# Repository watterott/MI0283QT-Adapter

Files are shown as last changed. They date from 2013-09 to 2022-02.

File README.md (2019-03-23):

# MI0283QT-Adapter
Adapter Board with 2.8" TFT-Display and Touchscreen/Touchpanel.

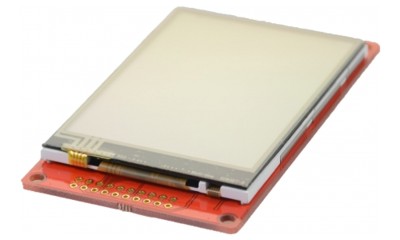
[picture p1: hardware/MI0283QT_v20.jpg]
MI0283QT-Adapter


* Multi-Inno MI0283QT 2.8" Display with Touchpanel (320x240 pixel)
* Backlight dimmable
* 3.3V - 5V tolerant IOs
* Power: 3.3V - 5V
* **MI0283QT-Adapter v1**
  * TI ADS7846/TSC2046 Touch-Controller
  * Interface: SPI/SSI (8-Bit or 9-Bit, up to 32MHz)
* **MI0283QT-Adapter v2**
  * NXP LPC1114 ARM Cortex-M0 with Open-Source Firmware
  * Interface: UART, I2C, SPI/SSI (8-Bit, Mode 3, up to 4MHz)
  * Pin-compatible with MI0283QT-Adapter v1
* Open-Source and released under the [Creative Commons Attribution Share-Alike License](https://creativecommons.org/licenses/by-sa/4.0/).
* **[Documentation on learn.watterott.com](https://learn.watterott.com)**

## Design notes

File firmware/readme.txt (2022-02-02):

Display Firmware
================
Firmware for MI0283QT-Adapter v2 and GLCD-Shield (with LPC1114 ARM Cortex-M0).
Visit https://github.com/watterott/MI0283QT-Adapter for updates.

Supported IDEs: CrossWorks for ARM and LPCXpresso/MCUxpresso

Documentation
-------------
  See docu.md

Third party software
--------------------
  CMSIS
  http://www.arm.com/products/processors/cortex-m/cortex-microcontroller-software-interface-standard.php

License
-------
  See license.txt

History
-------
  Jan 26 2022  v0.08  Added CMD_LCD_ENABLE + CMD_LCD_DISABLE.

  Jun 30 2014  v0.07  Bugfix in set_pwm.

  Jun 08 2014  v0.06  Bugfix in CMD_LCD_ORIENTATION+CMD_LCD_DRAWTEXT.
                      Bugfix in CMD_LCD_DRAWIMAGE.
                      Bugfix in touch calibration routine.
                      Added CMD_SYNC.

  Dec 09 2013  v0.05  Compiling with LPCXpresso.
                      Added interrupt/status output.

  Sep 18 2013  v0.04  Added ADC read function.

  Aug 18 2013  v0.03  Added byte order setting.

  Jun 22 2013  v0.02  TP/ENC/NAV have to be enabled.
                      Added light sensor support.

  Jun 17 2013  v0.01  First release.

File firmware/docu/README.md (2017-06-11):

# Display Firmware

**Documentation for Firmware v0.06+**

## Firmware Update

See [Firmware Update Guide](https://github.com/watterott/MI0283QT-Adapter/blob/master/firmware/update_guide/README.md).

The source code can be compiled with [CrossWorks for ARM](http://www.rowley.co.uk/arm/index.htm) or [LPCXpresso](http://www.lpcware.com/lpcxpresso) (registered Free Edition).

## Interfaces

The display can be controlled through 3 interfaces: I2C, SPI/SSI and UART. The default interface is I2C.
To activate SPI or UART set **CS+MOSI** or **CS+RX** to low after a reset or on power-up.
The current interface can be saved as default with the software command ```CMD_CTRL_SAVE``` and changed with ```CMD_CTRL_INTERFACE```.

**Default settings:**

* Interface: I2C
* Byte order: big endian
* I2C: address 0x20, max. 400 kHz
* SPI: Mode 3, max. 4 MHz @ 48 MHz system clock
* UART: 9600 baud (8N1)
* System clock: 48 MHz

**I2C activation:**

    - Set MOSI high + RX high + CS low
    - Reset: RST low -> wait 10 ms -> RST high

**SPI activation:**

    - Set MOSI low + RX high + CS low
    - Reset: RST low -> wait 10 ms -> RST high

**UART activation:**

    - Set RX low + MOSI high + CS low
    - Reset: RST low -> wait 10 ms -> RST high

## Examples

* [Arduino examples](https://github.com/watterott/MI0283QT-Adapter/tree/master/firmware/examples)

## Commands

Parameters have a 8 bit width, expect *color values* (RGB565) and *position values* (x,y,z,w,h,r) on screens bigger than 255 pixel in one direction. These are 16 bit width.

Commands that end with *FG* or *BG* need no color value.

Example: ```CMD_LCD_CLEAR``` has as parameter a 2 byte color value and ```CMD_LCD_CLEARFG``` fills the screen with the foreground color and ```CMD_LCD_CLEARBG``` with the background color.

### General Commands

    CMD_NOP1
    CMD_NOP2
No operation.

    CMD_SYNC
Returns ```CMD_SYNC``` (1 byte).

    CMD_VERSION
Get firmware version. Returns 4 bytes, for example ```0.12```.

    CMD_TEST
Start the test program. To exit send ```0``` and wait till the board responses with ```CMD_TEST``` (1 byte).

    CMD_STATUS
Get status. A reading clears the interrupt output. Returns 1 byte with ```FEATURE_LCD```, ```FEATURE_TP```, ```FEATURE_ENC```, ```FEATURE_NAV```, ```FEATURE_LDR``` set.

    CMD_FEATURES
Get features. Returns 1 byte with ```FEATURE_LCD```, ```FEATURE_TP```, ```FEATURE_ENC```, ```FEATURE_NAV```, ```FEATURE_LDR```, ```FEATURE_IRQ``` set.

    CMD_PIN
Set GPIO pin. Parameter: 1 byte (1=input, 2=read input, 3=output low, 4=output high, 5=IRQ output low active, 6=IRQ output high active)

    CMD_ADC
Read ADC channel. Parameter: 1 byte (4, 5, 7 or 255 for LDR)

    CMD_CTRL
General system settings/options. Parameter: 1 byte
* ```CMD_CTRL_SAVE```      - Save current settings to flash (sysclock, backlight, interface, baud rate, address, byte order, fg color, bg color, touchpanel calibration).
* ```CMD_CTRL_INTERFACE``` - Set interface. Parameter: 1 byte (```INTERFACE_UART```, ```INTERFACE_I2C```, ```INTERFACE_SPI```)
* ```CMD_CTRL_BAUDRATE```  - Set UART baud rate. Parameter: 4 bytes = 32 bit (9600...1000000)
* ```CMD_CTRL_ADDRESS```   - Set I2C address. Parameter: 1 byte
* ```CMD_CTRL_BYTEORDER``` - Set byte order. Parameter: 1 byte (0=big endian , 1=little endian)
* ```CMD_CTRL_SYSCLOCK```  - Set system clock in MHz. Parameter: 1 byte (12, 16, 24, 32, 36, 48)
* ```CMD_CTRL_FEATURES```  - Enable or disable features. Parameter: 1 byte (```FEATURE_LCD```, ```FEATURE_TP```, ```FEATURE_ENC```, ```FEATURE_NAV```, ```FEATURE_LDR```, ```FEATURE_IRQ```)

### Display Commands

    CMD_LCD_LED
Set or get display backlight power. Parameter: 1 byte (0-100 or 255 for reading)

    CMD_LCD_RESET
Reset the display controller.

    CMD_LCD_POWER
Set display panel power. Parameter: 1 byte (0=off, 1=on)

    CMD_LCD_RAWCMD
Send raw command to the display controller. Parameter: 1 byte
    
    CMD_LCD_RAWDAT
Send raw data to the display controller. Parameter: 1 byte
    
    CMD_LCD_ORIENTATION
Set display orientation. Parameter: 1 byte (0=0°, 9=90°, 18=180°, 27=270°)

Orientation dia

    CMD_LCD_WIDTH
Get display width. Returns always 2 bytes = 16 bit.
    
    CMD_LCD_HEIGHT
Get display height. Returns always 2 bytes = 16 bit.
    
    CMD_LCD_INVERT
Invert display. Parameter: 1 byte (0=off, 1=on)
    
    CMD_LCD_FGCOLOR
Set foreground color. Parameter: color (2 byte, RGB565)
    
    CMD_LCD_BGCOLOR
Set background color. Parameter: color (2 byte, RGB565)
    
    CMD_LCD_TERMINAL
Start terminal mode. To exit send *0* and the board responses with ```CMD_LCD_TERMINAL```.

    CMD_LCD_DRAWIMAGE
Draw image. Parameter: x0, y0, w, h, color_mode, color...
    
    CMD_LCD_CLEAR
    CMD_LCD_CLEARFG
    CMD_LCD_CLEARBG
Clear display. Parameter: [color]

    CMD_LCD_DRAWPIXEL
    CMD_LCD_DRAWPIXELFG
    CMD_LCD_DRAWPIXELBG
Draw pixel. Parameter: x0, y0, [color]

    CMD_LCD_DRAWLINE
    CMD_LCD_DRAWLINEFG
    CMD_LCD_DRAWLINEBG
Draw line. Parameter: x0, y0, x1, y1, [color]

    CMD_LCD_DRAWLINES
    CMD_LCD_DRAWLINESFG
    CMD_LCD_DRAWLINESBG
Draw lines. Parameter: [color], n, x0, y0...xn, yn

    CMD_LCD_DRAWRECT
    CMD_LCD_DRAWRECTFG
    CMD_LCD_DRAWRECTBG
Draw rectangle. Parameter: x0, y0, w, h, [color]

    CMD_LCD_FILLRECT
    CMD_LCD_FILLRECTFG
    CMD_LCD_FILLRECTBG
Fill rectangle. Parameter: x0, y0, w, h, [color]

    CMD_LCD_DRAWRNDRECT
    CMD_LCD_DRAWRNDRECTFG
    CMD_LCD_DRAWRNDRECTBG
Draw round rectangle. Parameter: x0, y0, w, h, radius, [color]

    CMD_LCD_FILLRNDRECT
    CMD_LCD_FILLRNDRECTFG
    CMD_LCD_FILLRNDRECTBG
Fill round rectangle. Parameter: x0, y0, w, h, radius, [color]

    CMD_LCD_DRAWCIRCLE
    CMD_LCD_DRAWCIRCLEFG
    CMD_LCD_DRAWCIRCLEBG
Draw circle. Parameter: x0, y0, radius, [color]

    CMD_LCD_FILLCIRCLE
    CMD_LCD_FILLCIRCLEFG
    CMD_LCD_FILLCIRCLEBG
Fill circle. Parameter: x0, y0, radius, [color]

    CMD_LCD_DRAWELLIPSE
    CMD_LCD_DRAWELLIPSEFG
    CMD_LCD_DRAWELLIPSEBG
Draw ellipse. Parameter: x0, y0, radius_x, radius_y, [color]

    CMD_LCD_FILLELLIPSE
    CMD_LCD_FILLELLIPSEFG
    CMD_LCD_FILLELLIPSEBG
Fill ellipse. Parameter: x0, y0, radius_x, radius_y, [color]

    CMD_LCD_DRAWTEXT
    CMD_LCD_DRAWTEXTFG
    CMD_LCD_DRAWTEXTBG
Draw text. Parameter: [fg_color], [bg_color], x0, y0, size_clear (0x7F=size, 0x80=clear background), length, text

    CMD_LCD_DRAWSTRING
    CMD_LCD_DRAWSTRINGFG
    CMD_LCD_DRAWSTRINGBG
Draw string. Parameter: [fg_color], [bg_color], x0, y0, size_clear (0x7F=size, 0x80=clear background), text (end with 0x00)

### Touch-Panel Commands

Note: To activate the touch panel use ```CMD_CTRL + CMD_CTRL_FEATURES``` and set ```FEATURE_TP```.
      The touch panel will be checked in background continuously and the result can be read with the following commands.

    CMD_TP_POS
Get last position and pressure. Returns x, y, z.

    CMD_TP_X
Get last x position. Returns x.

    CMD_TP_Y
Get last y position. Returns y.

    CMD_TP_Z
Get current pressure. Returns z.

    CMD_TP_WAITPRESS
Wait till press and get position after press. Returns x, y.

    CMD_TP_WAITRELEASE
Wait till release and get position after release. Returns x, y.

    CMD_TP_WAITMOVE
Wait till move and get direction after move. Returns 1 byte (0x01=x-, 0x02=x+, 0x04=y-, 0x08=y+).

    CMD_TP_CALIBRATE
Calibrate touch panel. This will not save the calibration data to flash (see ```CMD_CTRL + CMD_CTRL_SAVE```). Returns ```CMD_TP_CALIBRATE``` after the calibration is completed or when *0* is sent to exit.

### Rotary-Encoder Commands

Note: To activate the rotary encoder use ```CMD_CTRL + CMD_CTRL_FEATURES``` and set ```FEATURE_ENC```.
      The encoder state will be checked in background continuously and the result can be read with the following commands.

    CMD_ENC_POS
Get position and switch state. Returns 2 bytes: position (-127...+127), state (0x01=press, 0x02=long press).

    CMD_ENC_SW
Get switch state. Returns 1 byte (0x01=press, 0x02=long press)

    CMD_ENC_WAITPRESS
Wait till press. Returns 2 bytes: position (-127...+127), state (0x01=press, 0x02=long press).

    CMD_ENC_WAITRELEASE
Wait till release. Returns 2 bytes: position (-127...+127), state (0x01=press, 0x02=long press).

### Navigation-Switch / Joystick Commands

Note: To activate the navigation switch use ```CMD_CTRL + CMD_CTRL_FEATURES``` and set ```FEATURE_NAV```.
      The switch will be checked in background continuously and the result can be read with the following commands.

    CMD_NAV_POS
Get position and switch state. Returns 3 bytes: left-right position (-127...+127), down-up position (-127...+127), state (0x01=press, 0x02=long press, 0x10=right, 0x20=left, 0x40=up, 0x80=down).

    CMD_NAV_SW
Get switch state. Returns 1 byte: state (0x01=press, 0x02=long press, 0x10=right, 0x20=left, 0x40=up, 0x80=down)

    CMD_NAV_WAITPRESS
Wait till press. Returns 3 bytes: left-right position (-127...+127), down-up position (-127...+127), state (0x01=press, 0x02=long press, 0x10=right, 0x20=left, 0x40=up, 0x80=down).

    CMD_NAV_WAITRELEASE
Wait till release. Returns 3 bytes: left-right position (-127...+127), down-up position (-127...+127), state (0x01=press, 0x02=long press, 0x10=right, 0x20=left, 0x40=up, 0x80=down).

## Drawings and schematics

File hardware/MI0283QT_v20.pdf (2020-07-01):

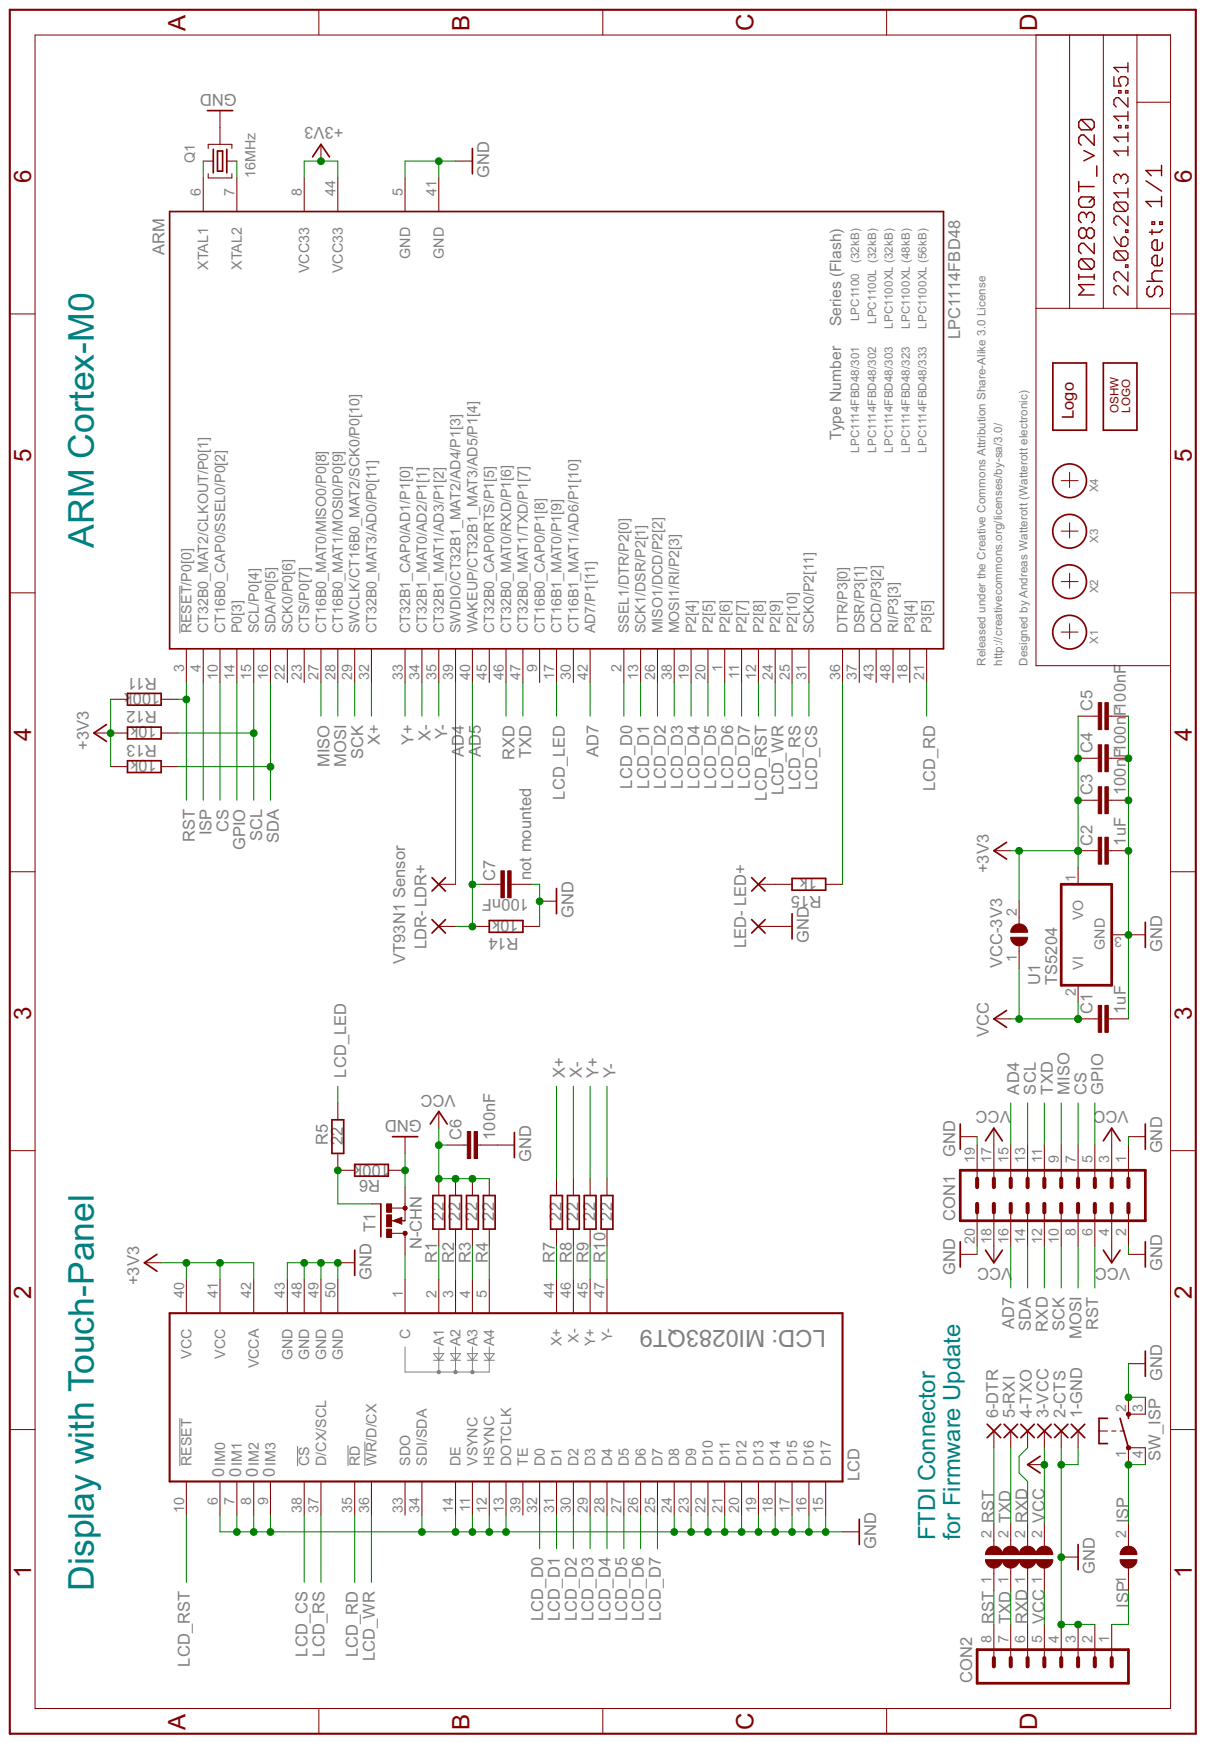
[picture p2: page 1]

Type Number Series (Flash)

Released under the Creative Commons Attribution Share-Alike 3.0 License

Display with Touch-Panel ARM Cortex-M0

Designed by Andreas Watterott (Watterott electronic)

CT16B1_MAT0/P1[9] 17 CT16B0_CAP0/P1[8] 9 CT32B0_MAT1/TXD/P1[7] 47 CT32B0_MAT0/RXD/P1[6] 46 CT32B0_CAP0/RTS/P1[5] 45 WAKEUP/CT32B1_MAT3/AD5/P1[4] 40 SWDIO/CT32B1_MAT2/AD4/P1[3] 39 CT32B1_MAT1/AD3/P1[2] 35 CT32B1_MAT0/AD2/P1[1] 34 CT32B1_CAP0/AD1/P1[0] 33

http://creativecommons.org/licenses/by-sa/3.0/

P2[9] 24 P2[8] 12 P2[7] 11 P2[6] 1 P2[5] 20 P2[4] 19 MOSI1/RI/P2[3] 38 MISO1/DCD/P2[2] 26 SCK1/DSR/P2[1] 13 SSEL1/DTR/P2[0] 2

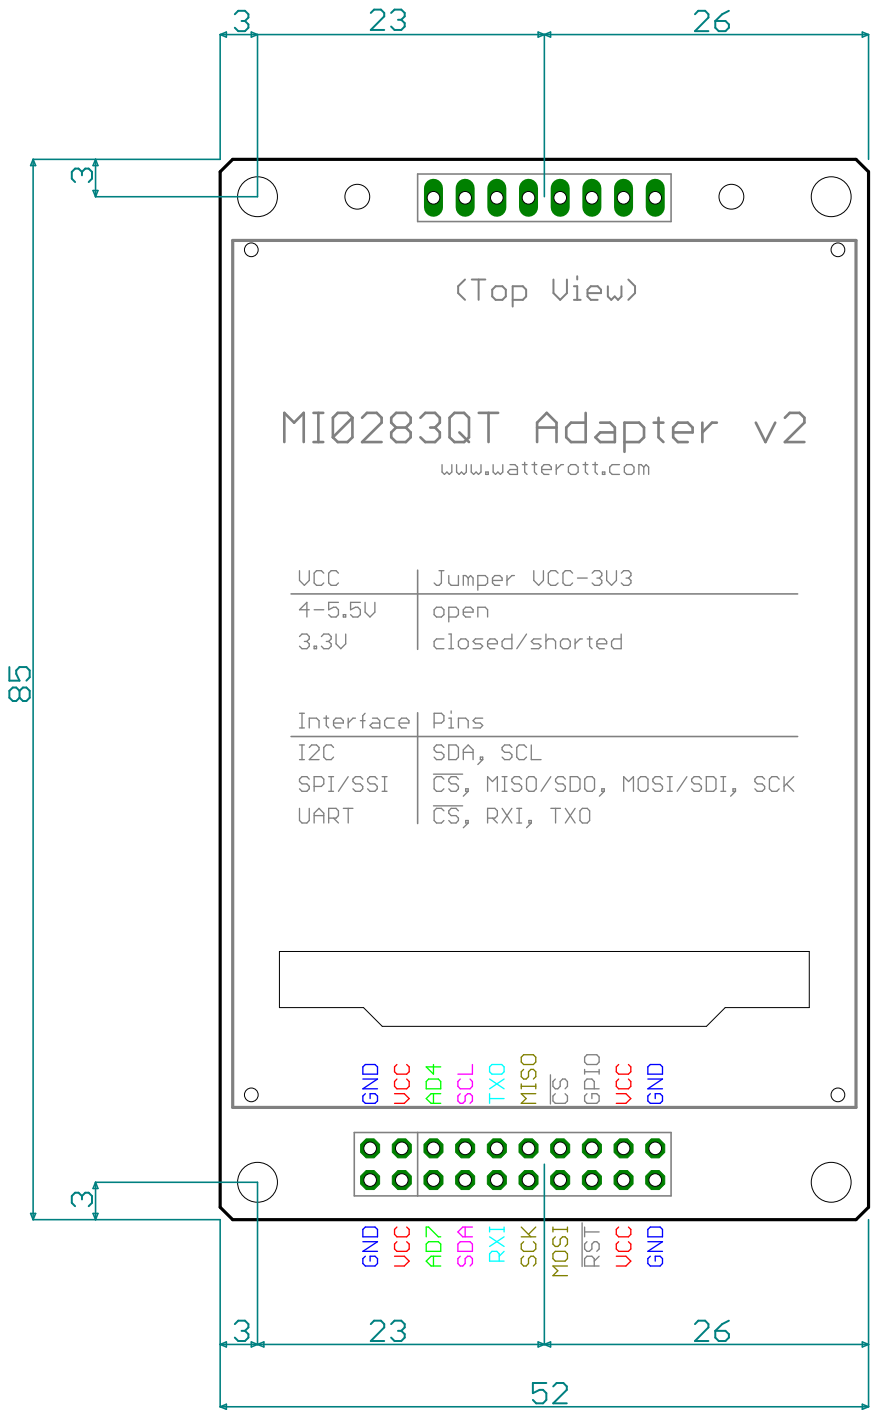
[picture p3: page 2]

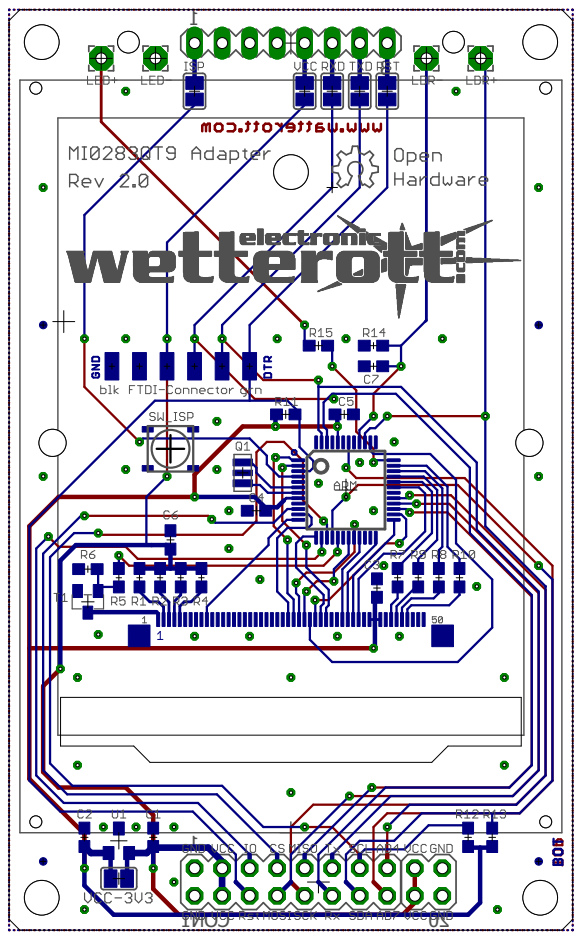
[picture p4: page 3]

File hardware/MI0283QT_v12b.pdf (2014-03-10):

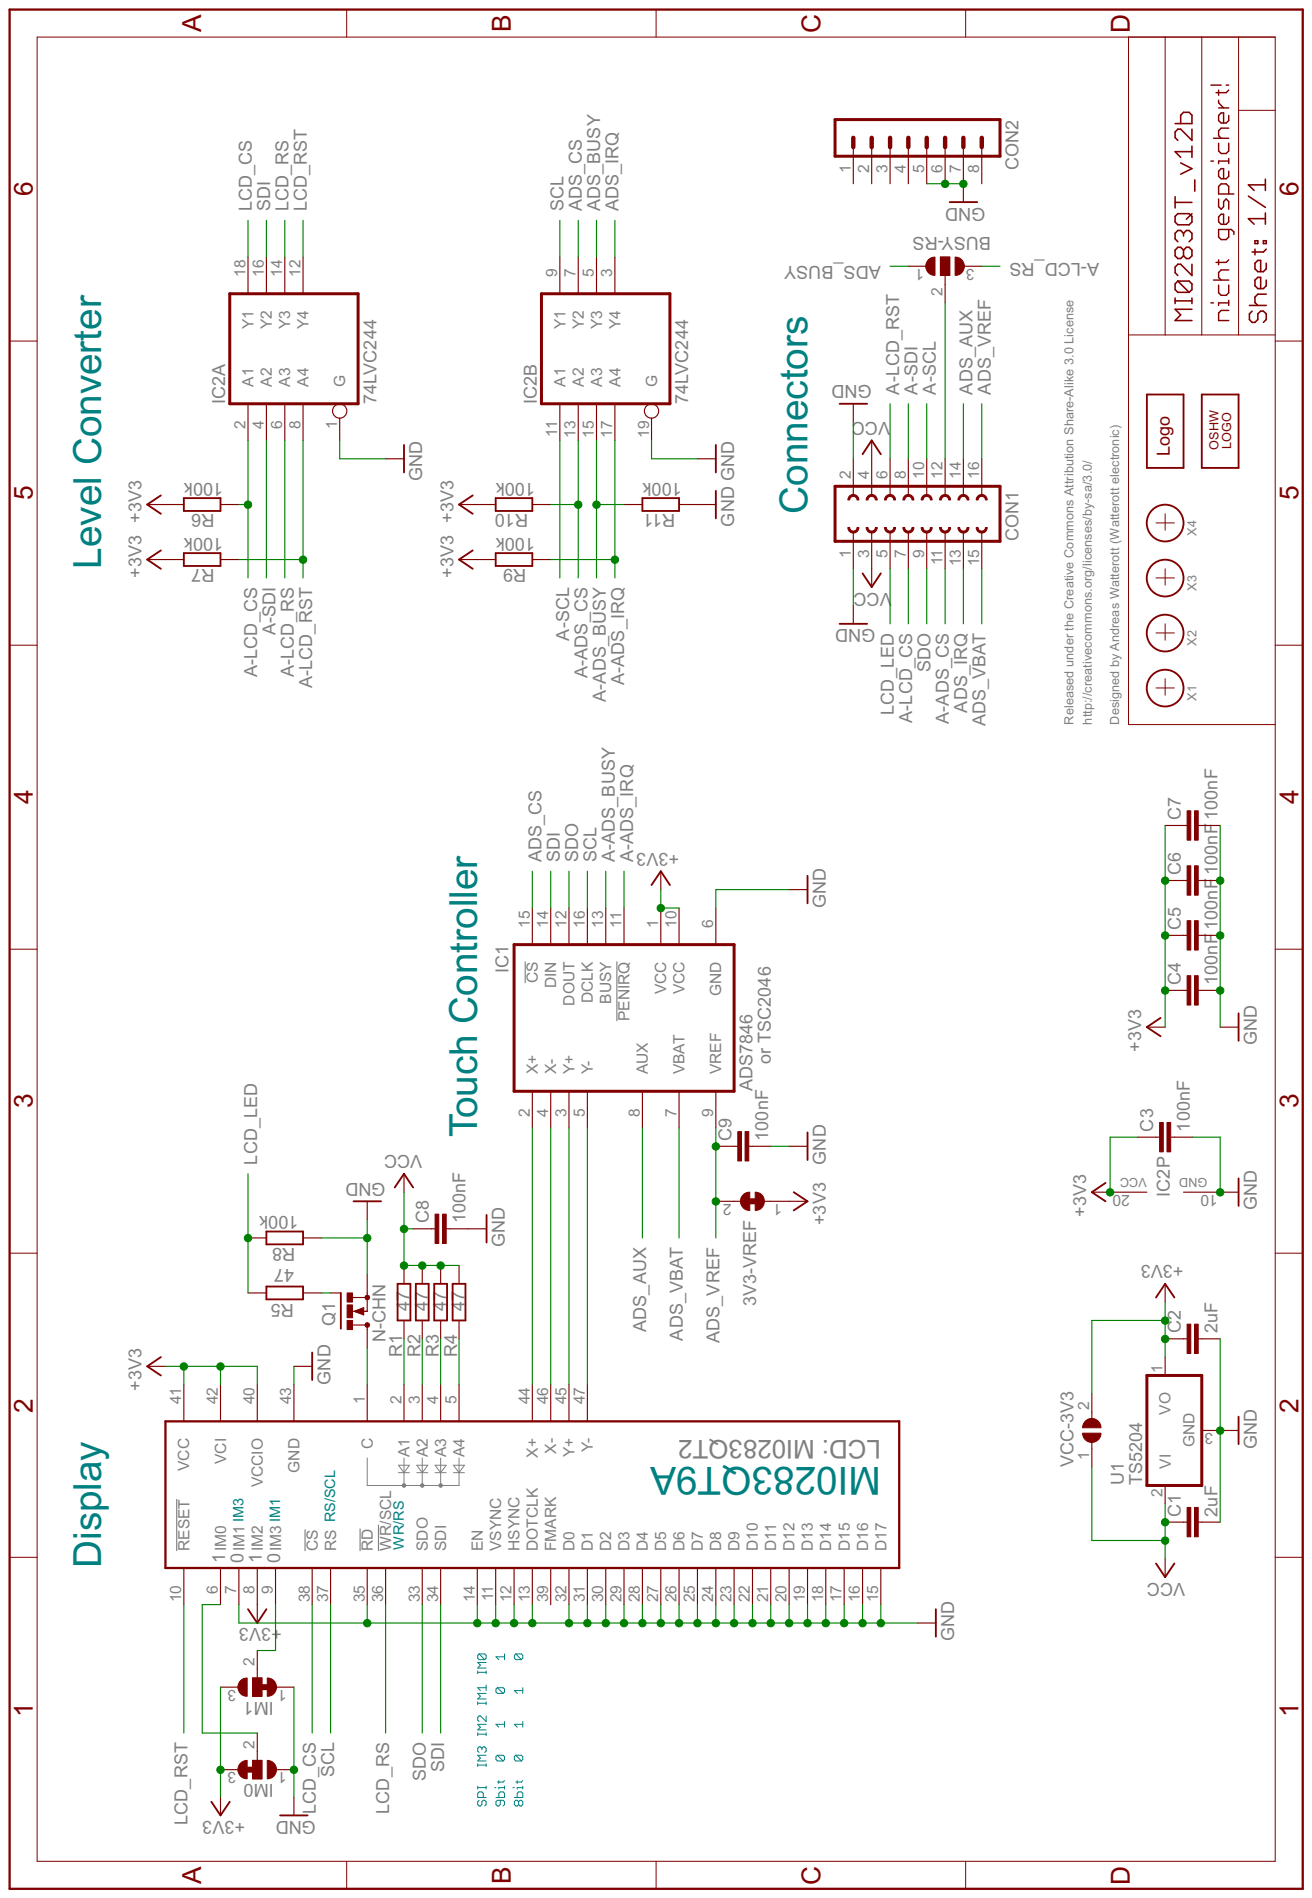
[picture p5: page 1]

Released under the Creative Commons Attribution Share-Alike 3.0 License

http://creativecommons.org/licenses/by-sa/3.0/ Designed by Andreas Watterott (Watterott electronic)

IM1 RS/SCL WR/RS

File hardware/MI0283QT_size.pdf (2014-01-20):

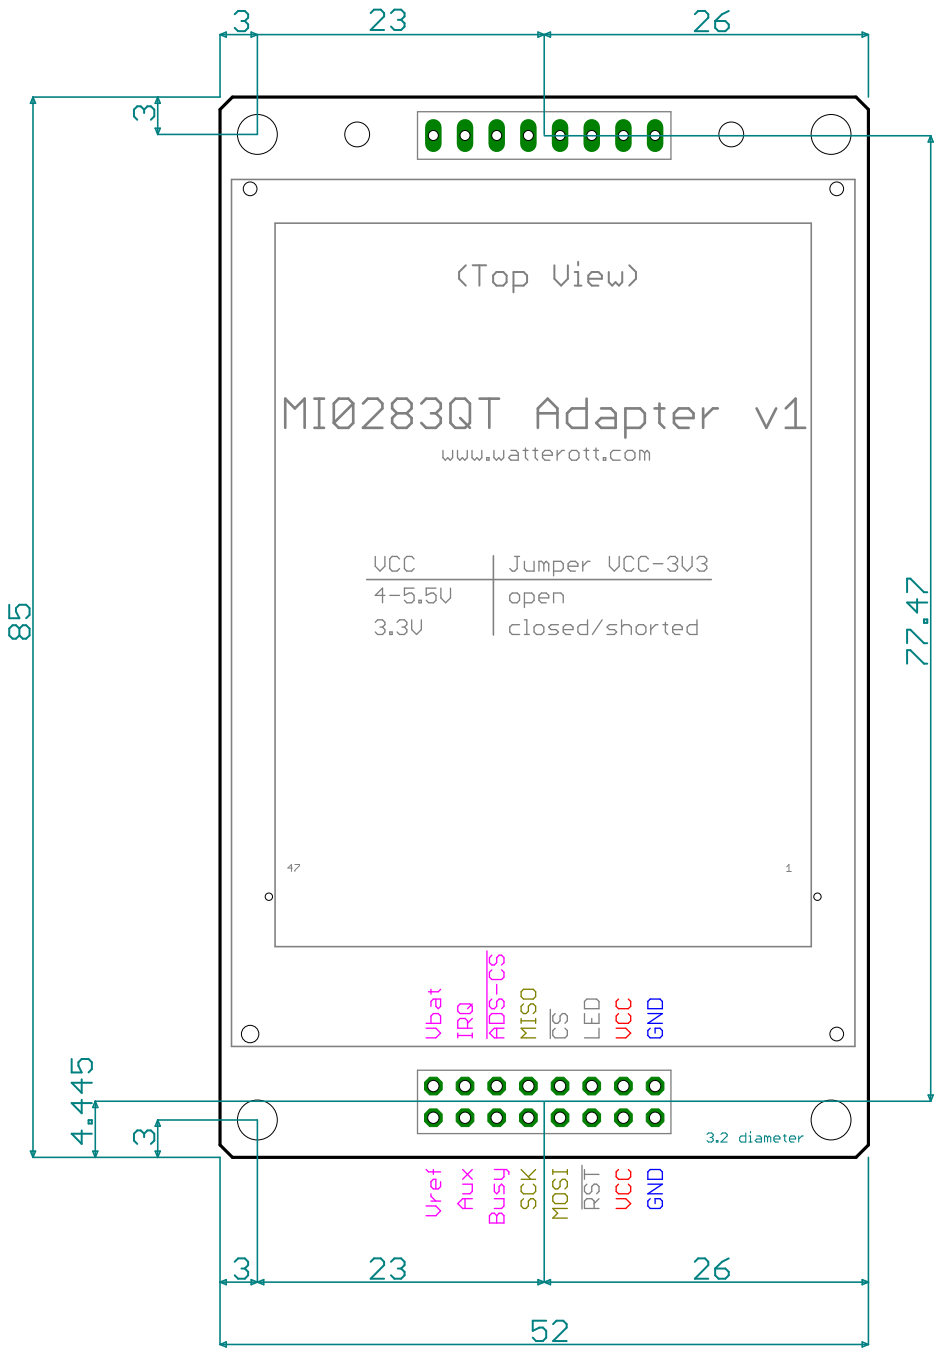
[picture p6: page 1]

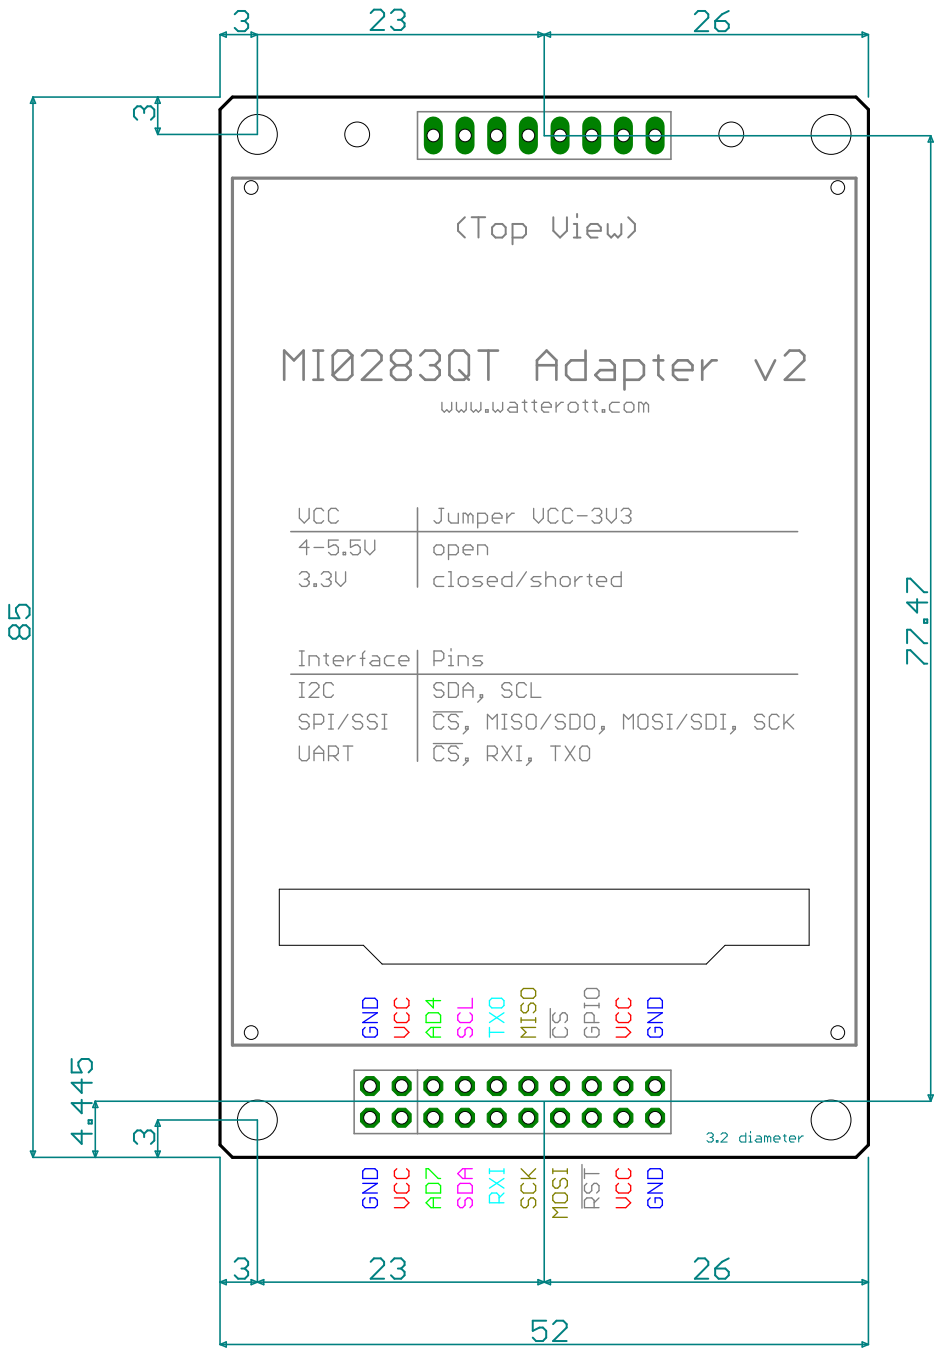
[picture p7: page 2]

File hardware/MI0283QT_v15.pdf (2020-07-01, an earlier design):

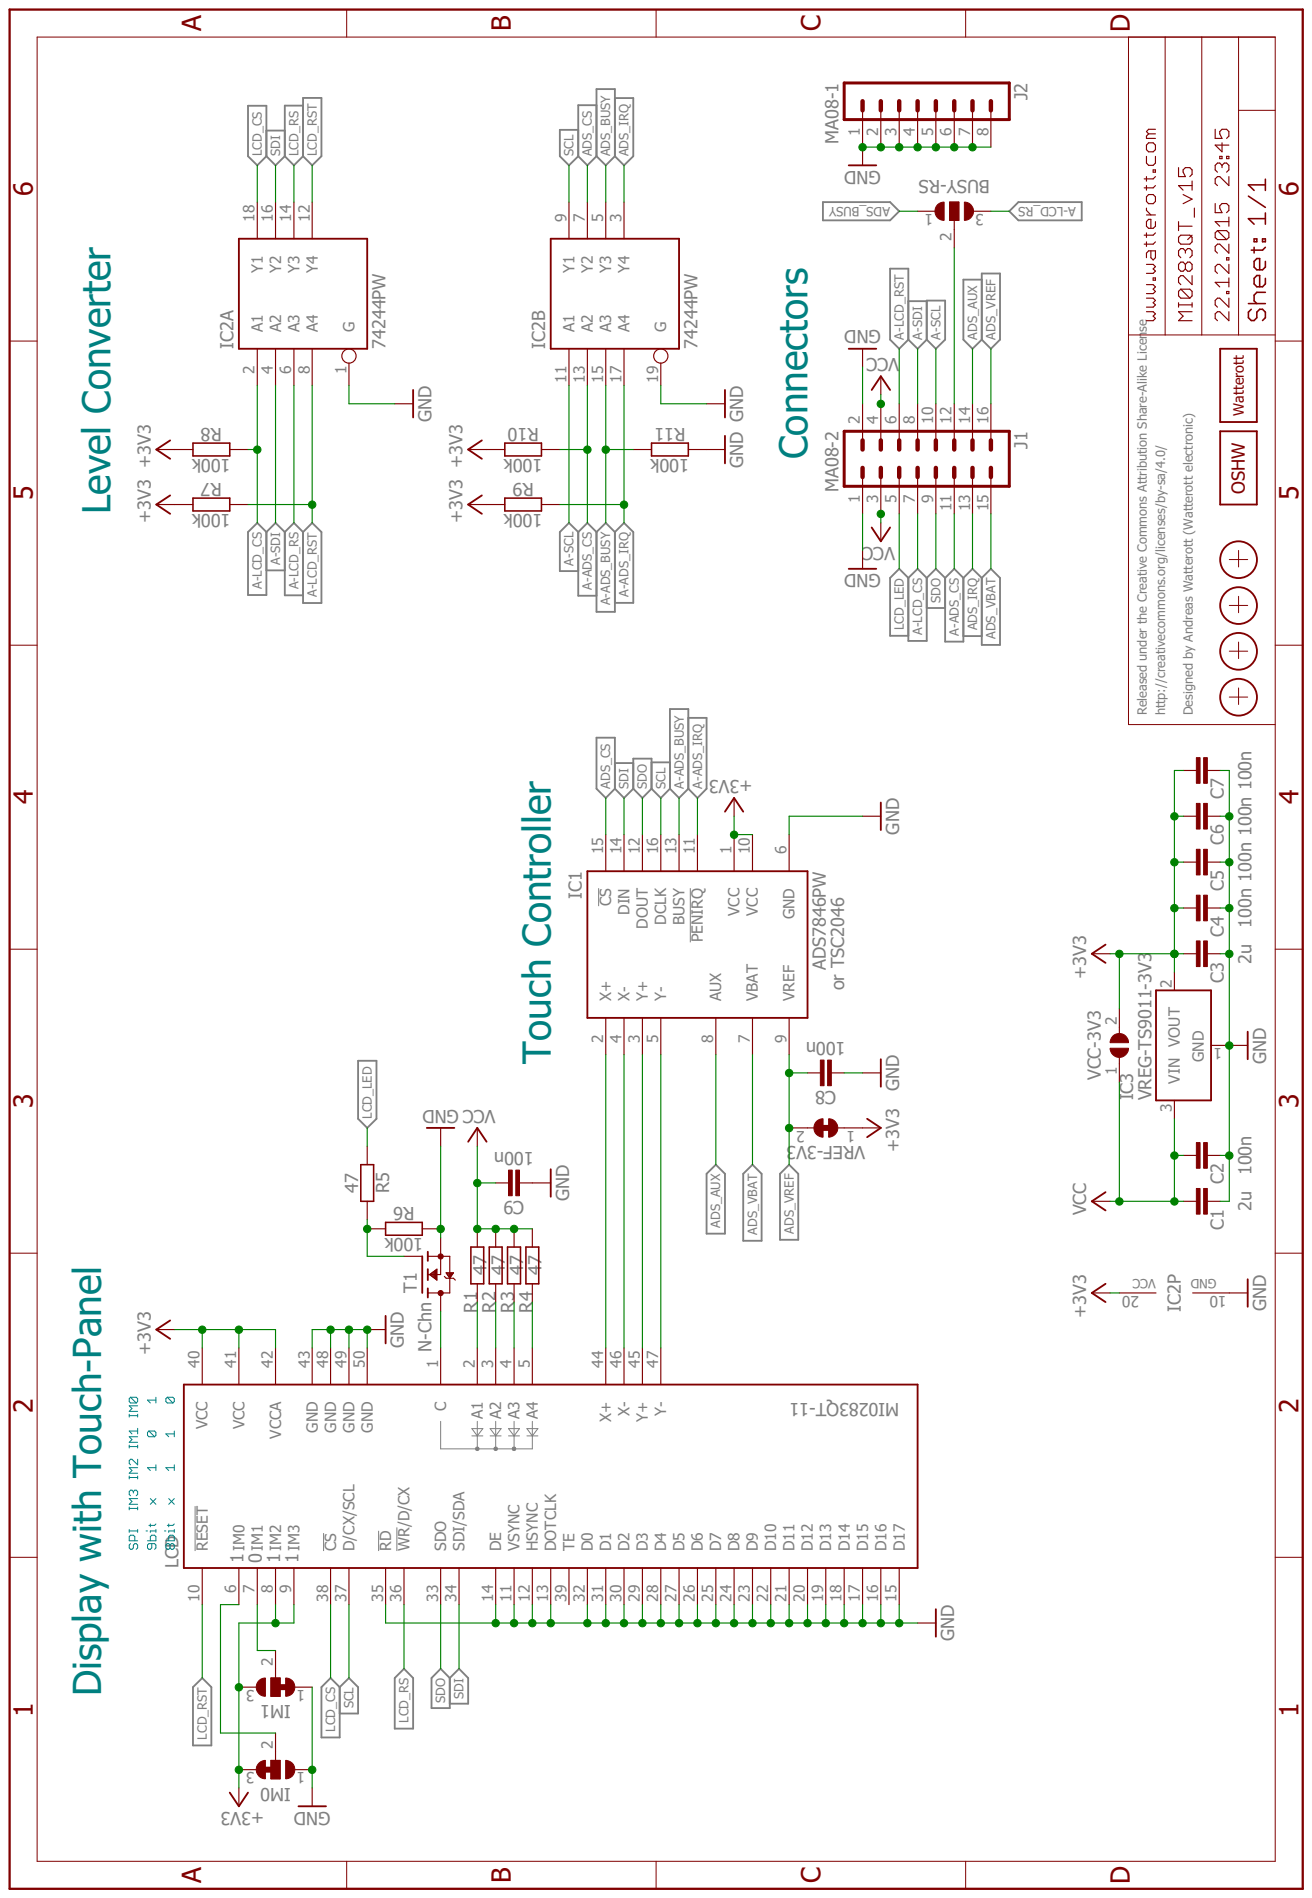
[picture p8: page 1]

Released under the Creative Commons Attribution Share-Alike License http://creativecommons.org/licenses/by-sa/4.0/ Designed by Andreas Watterott (Watterott electronic)

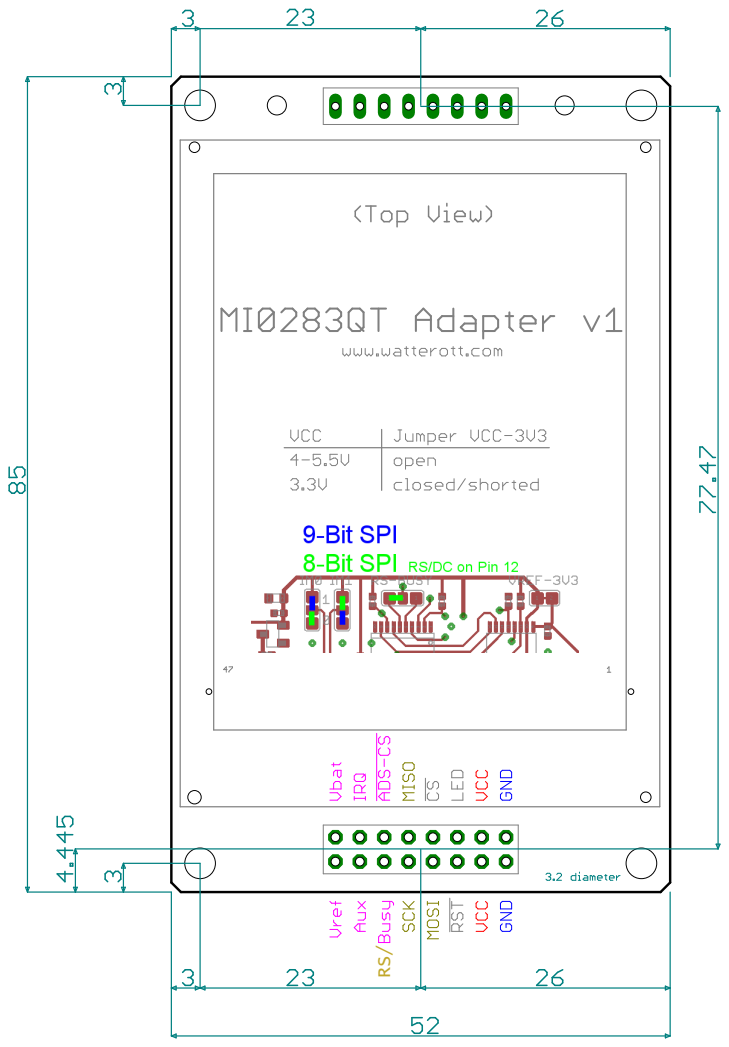
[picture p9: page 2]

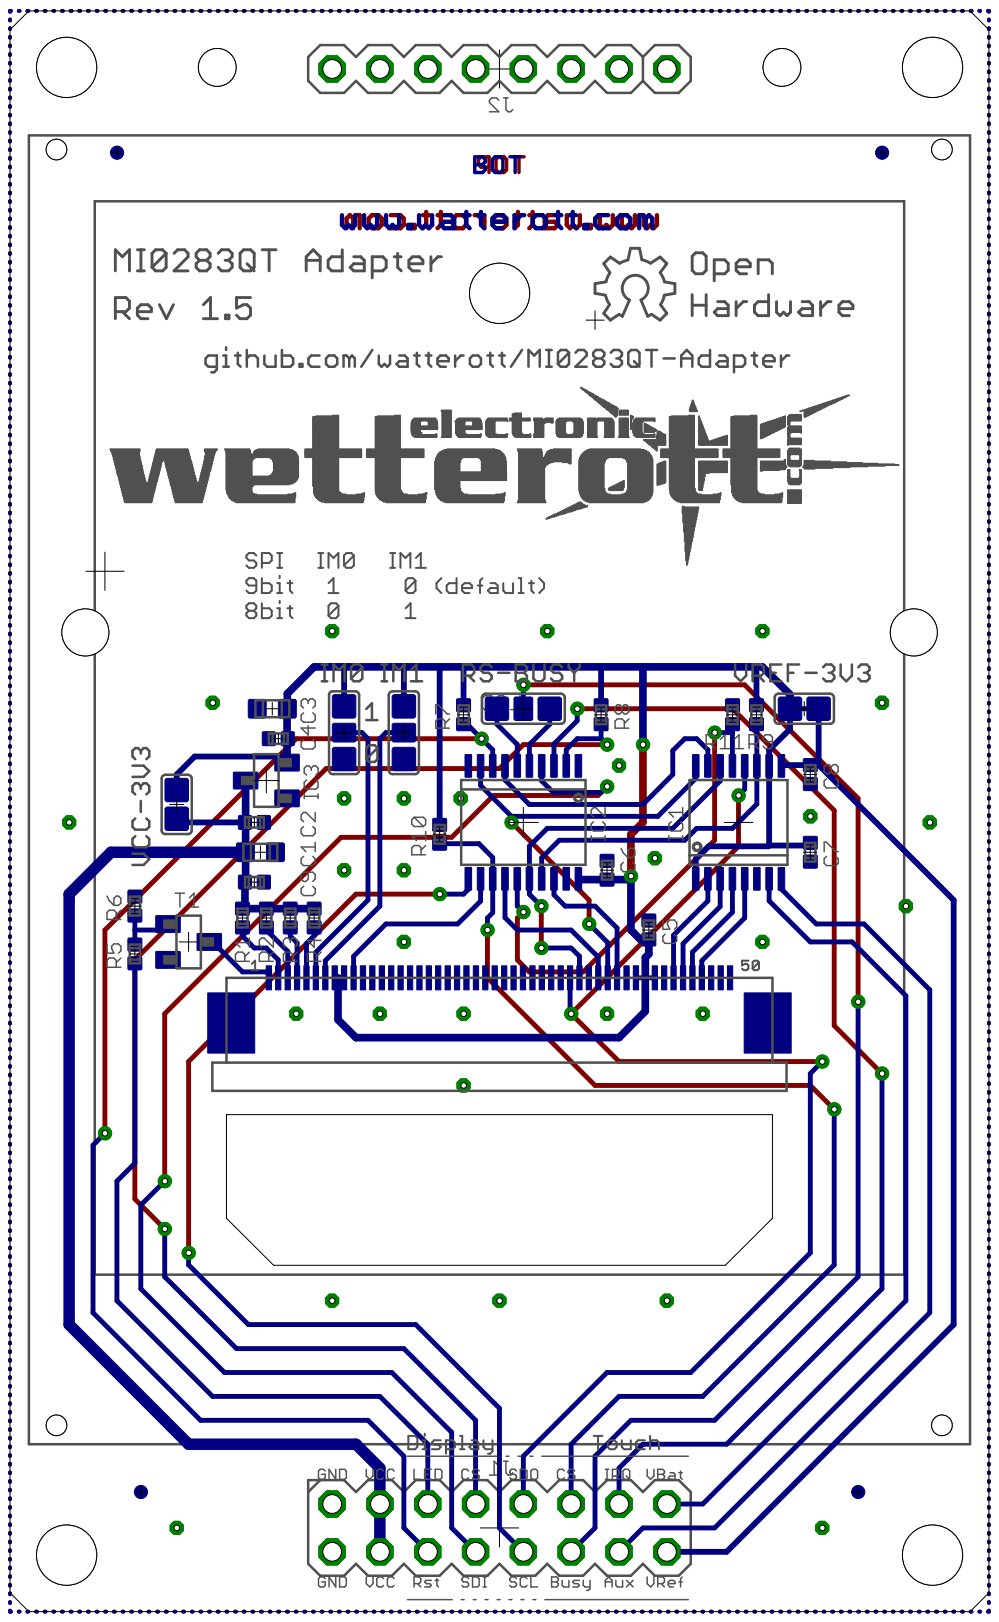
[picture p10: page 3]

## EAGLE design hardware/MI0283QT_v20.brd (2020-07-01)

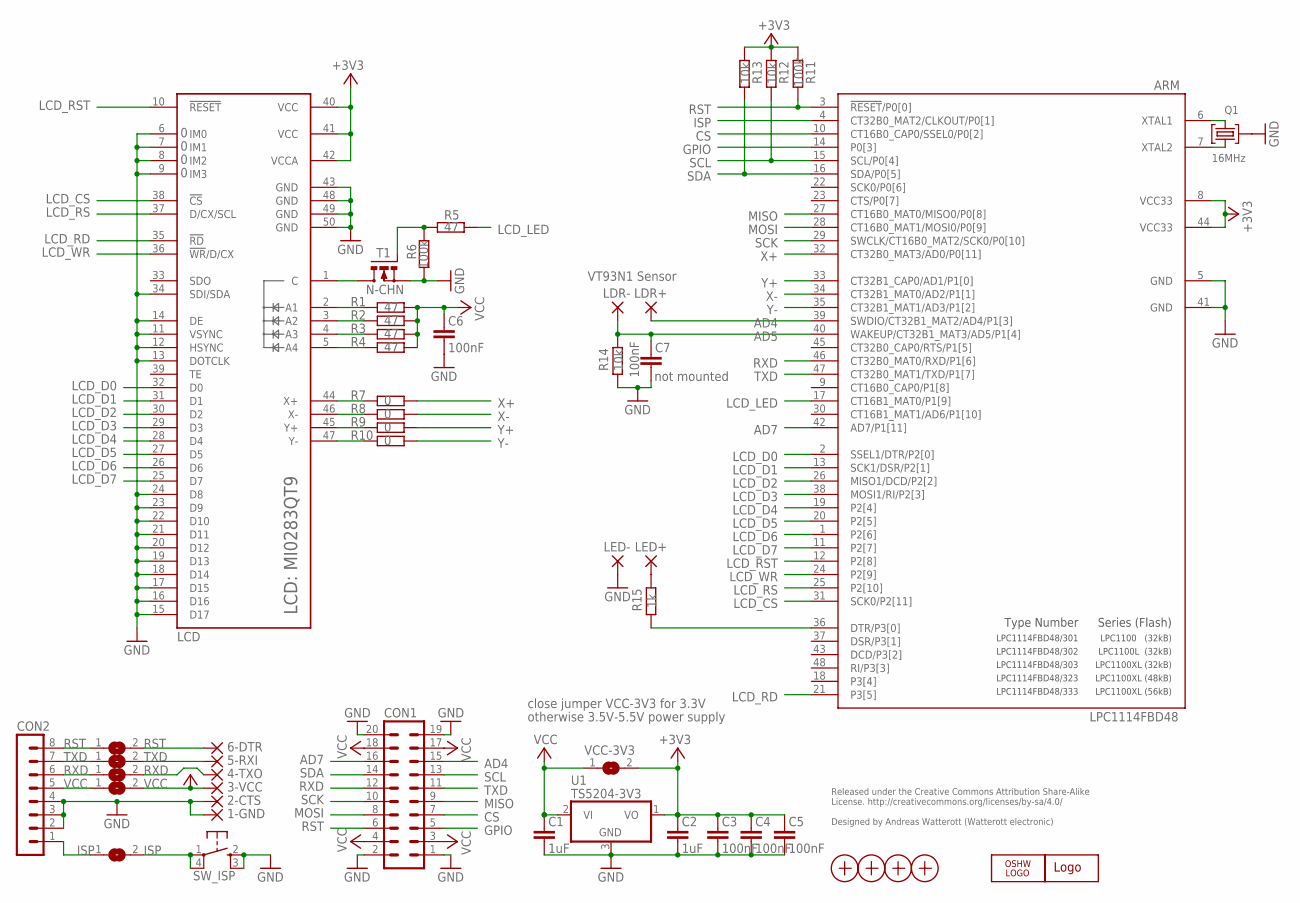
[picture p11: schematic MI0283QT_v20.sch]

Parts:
1-GND, 2-CTS, 3-VCC, 4-TXO, 5-RXI, 6-DTR: WIREPADSMD1,27-254; SMD1,27-2,54
ARM: LPC1114FBD48; LQFP48
C1, C2: 1uF; C0603
C3, C4, C5, C6, C7: 100nF; C0603
CON1: MA10-2
CON2: MA08-1
ISP: SJ
LCD: MI0283QT9
LDR+: WIREPAD2,15/1,0; 2,15/1,0
LDR-: WIREPAD2,15/1,0; 2,15/1,0
LED+: WIREPAD2,15/1,0; 2,15/1,0
LED-: WIREPAD2,15/1,0; 2,15/1,0
LOGO1: OSHW_LOGO_6MILX0150-NT; OSHW_6X150_NOTEXT
Q1: 16MHz; SMD_OSC_35X15
R1, R2, R3, R4, R5: 47; R0603
R6, R11: 100k; R0603
R7, R8, R9, R10: 0; R0603
R12, R13, R14: 10k; R0603
R15: 1k; R0603
RST: SJ
RXD: SJ
SW_ISP: SW_SMDS; SW_SMD4@1
T1: N-CHN; MICRO3
TXD: SJ
U1: TS5204-3V3; SOT23
U$1: WE-LOGO
VCC: SJ
VCC-3V3: SJ
X1, X2, X3, X4: PASSER

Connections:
+3V3: ARM.8 (VCC33), ARM.44 (VCC33), C2.1, C3.1, C4.1, C5.1, LCD.40 (VCC), LCD.41 (VCC), LCD.42 (VCCA), R11.2, R12.2, R13.2, U1.1 (VO), VCC-3V3.2
AD4: ARM.39 (SWDIO/CT32B1_MAT2/AD4/P1[3]), CON1.15, LDR+.1
AD5: ARM.40 (WAKEUP/CT32B1_MAT3/AD5/P1[4]), C7.1, LDR-.1, R14.2
AD7: ARM.42 (AD7/P1[11]), CON1.16
C: LCD.1 (C), T1.3 (D)
CS: ARM.10 (CT16B0_CAP0/SSEL0/P0[2]), CON1.7
C_ISP: CON2.1, ISP.1
C_RST: CON2.8, RST.1
C_RXD: CON2.6, RXD.1
C_TXD: CON2.7, TXD.1
C_VCC: CON2.5, VCC.1
GND: 1-GND.1, 2-CTS.1, ARM.5 (GND), ARM.41 (GND), C1.2, C2.2, C3.2, C4.2, C5.2, C6.2, C7.2, CON1.1, CON1.2, CON1.19, CON1.20, CON2.2, CON2.3, CON2.4, LCD.6 (IM0), LCD.7 (IM1), LCD.8 (IM2), LCD.9 (IM3), LCD.11 (VSYNC), LCD.12 (HSYNC), LCD.13 (DOTCLK), LCD.14 (DE), LCD.15 (D17), LCD.16 (D16), LCD.17 (D15), LCD.18 (D14), LCD.19 (D13), LCD.20 (D12), LCD.21 (D11), LCD.22 (D10), LCD.23 (D9), LCD.24 (D8), LCD.34 (SDI/SDA), LCD.43 (GND), LCD.48 (GND), LCD.49 (GND), LCD.50 (GND), LED-.1, Q1.GND, R6.2, R14.1, SW_ISP.2 (S), SW_ISP.3 (S1), T1.2 (S), U1.3 (GND)
GPIO: ARM.14 (P0[3]), CON1.5
ISP: ARM.4 (CT32B0_MAT2/CLKOUT/P0[1]), ISP.2, SW_ISP.1, SW_ISP.4 (P1)
LCD_CS: ARM.31 (SCK0/P2[11]), LCD.38 (!CS)
LCD_D0: ARM.2 (SSEL1/DTR/P2[0]), LCD.32 (D0)
LCD_D1: ARM.13 (SCK1/DSR/P2[1]), LCD.31 (D1)
LCD_D2: ARM.26 (MISO1/DCD/P2[2]), LCD.30 (D2)
LCD_D3: ARM.38 (MOSI1/RI/P2[3]), LCD.29 (D3)
LCD_D4: ARM.19 (P2[4]), LCD.28 (D4)
LCD_D5: ARM.20 (P2[5]), LCD.27 (D5)
LCD_D6: ARM.1 (P2[6]), LCD.26 (D6)
LCD_D7: ARM.11 (P2[7]), LCD.25 (D7)
LCD_LED: ARM.17 (CT16B1_MAT0/P1[9]), R5.2
LCD_RD: ARM.21 (P3[5]), LCD.35 (!RD)
LCD_RS: ARM.25 (P2[10]), LCD.37 (D/CX/SCL)
LCD_RST: ARM.12 (P2[8]), LCD.10 (!RESET)
LCD_WR: ARM.24 (P2[9]), LCD.36 (!WR!/D/CX)
LED: ARM.36 (DTR/P3[0]), R15.1
LEDPWM: R5.1, R6.1, T1.1 (G)
LED_A1: LCD.2 (A1), R1.1
LED_A2: LCD.3 (A2), R2.1
LED_A3: LCD.4 (A3), R3.1
LED_A4: LCD.5 (A4), R4.1
MISO: ARM.27 (CT16B0_MAT0/MISO0/P0[8]), CON1.9
MOSI: ARM.28 (CT16B0_MAT1/MOSI0/P0[9]), CON1.8
unnamed: ARM.6 (XTAL1), Q1.2
unnamed: ARM.7 (XTAL2), Q1.1
unnamed: LED+.1, R15.2
RST: 6-DTR.1, ARM.3 (!RESET!/P0[0]), CON1.6, R11.1, RST.2
RXD: 4-TXO.1, ARM.46 (CT32B0_MAT0/RXD/P1[6]), CON1.12, RXD.2
SCK: ARM.29 (SWCLK/CT16B0_MAT2/SCK0/P0[10]), CON1.10
SCL: ARM.15 (SCL/P0[4]), CON1.13, R12.1
SDA: ARM.16 (SDA/P0[5]), CON1.14, R13.1
TXD: 5-RXI.1, ARM.47 (CT32B0_MAT1/TXD/P1[7]), CON1.11, TXD.2
VCC: 3-VCC.1, C1.1, C6.1, CON1.3, CON1.4, CON1.17, CON1.18, R1.2, R2.2, R3.2, R4.2, U1.2 (VI), VCC.2, VCC-3V3.1
X+: ARM.32 (CT32B0_MAT3/AD0/P0[11]), R7.2
X-: ARM.34 (CT32B1_MAT0/AD2/P1[1]), R8.2
XM: LCD.46 (X-), R8.1
XP: LCD.44 (X+), R7.1
Y+: ARM.33 (CT32B1_CAP0/AD1/P1[0]), R9.2
Y-: ARM.35 (CT32B1_MAT1/AD3/P1[2]), R10.2
YM: LCD.47 (Y-), R10.1
YP: LCD.45 (Y+), R9.1

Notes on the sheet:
Released under the Creative Commons Attribution Share-Alike License. http://creativecommons.org/licenses/by-sa/4.0/ Designed by Andreas Watterott (Watterott electronic)
LPC1100 (32kB)
LPC1100L (32kB)
LPC1100XL (32kB)
LPC1100XL (48kB)
LPC1100XL (56kB)
Type Number
Series (Flash)
LPC1114FBD48/301
LPC1114FBD48/302
LPC1114FBD48/303
LPC1114FBD48/323
LPC1114FBD48/333
not mounted
VT93N1 Sensor
otherwise 3.5V-5.5V power supply
close jumper VCC-3V3 for 3.3V

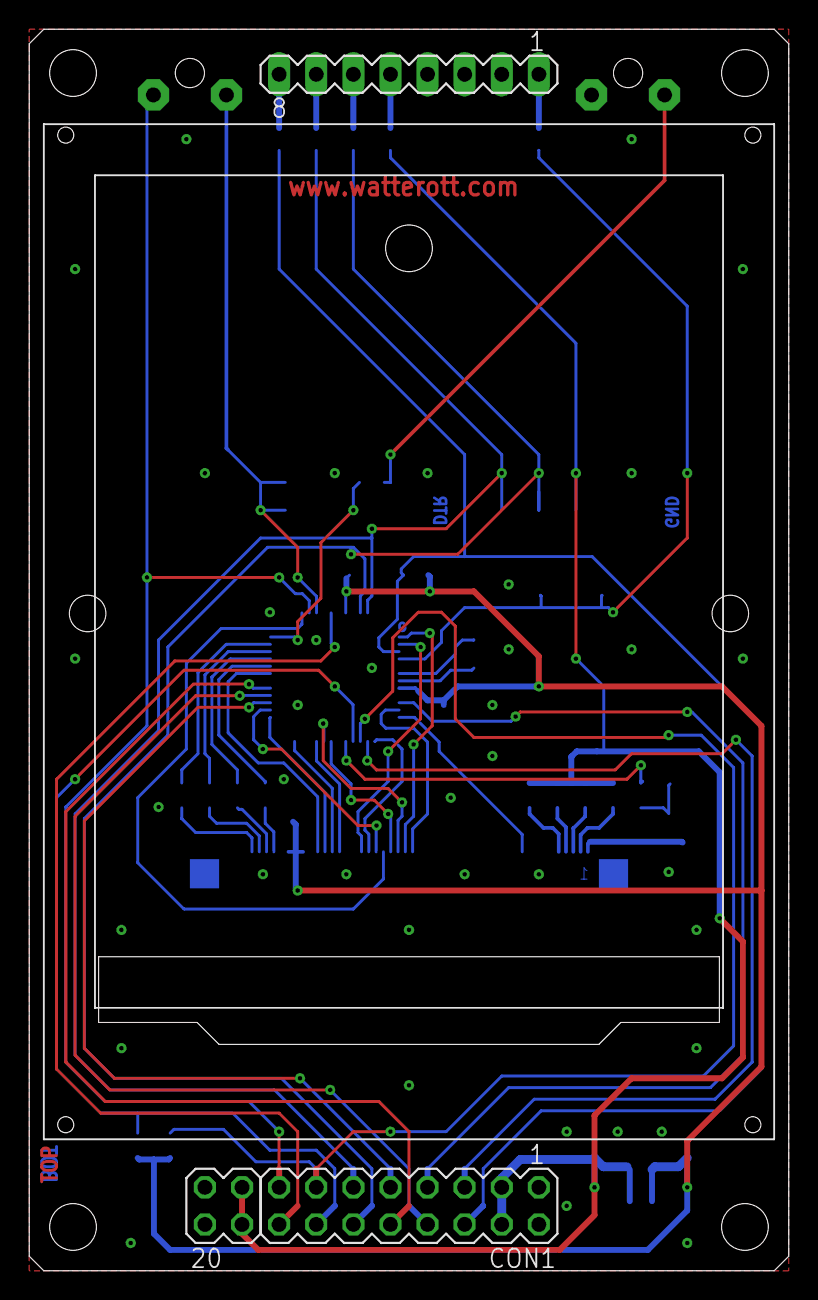
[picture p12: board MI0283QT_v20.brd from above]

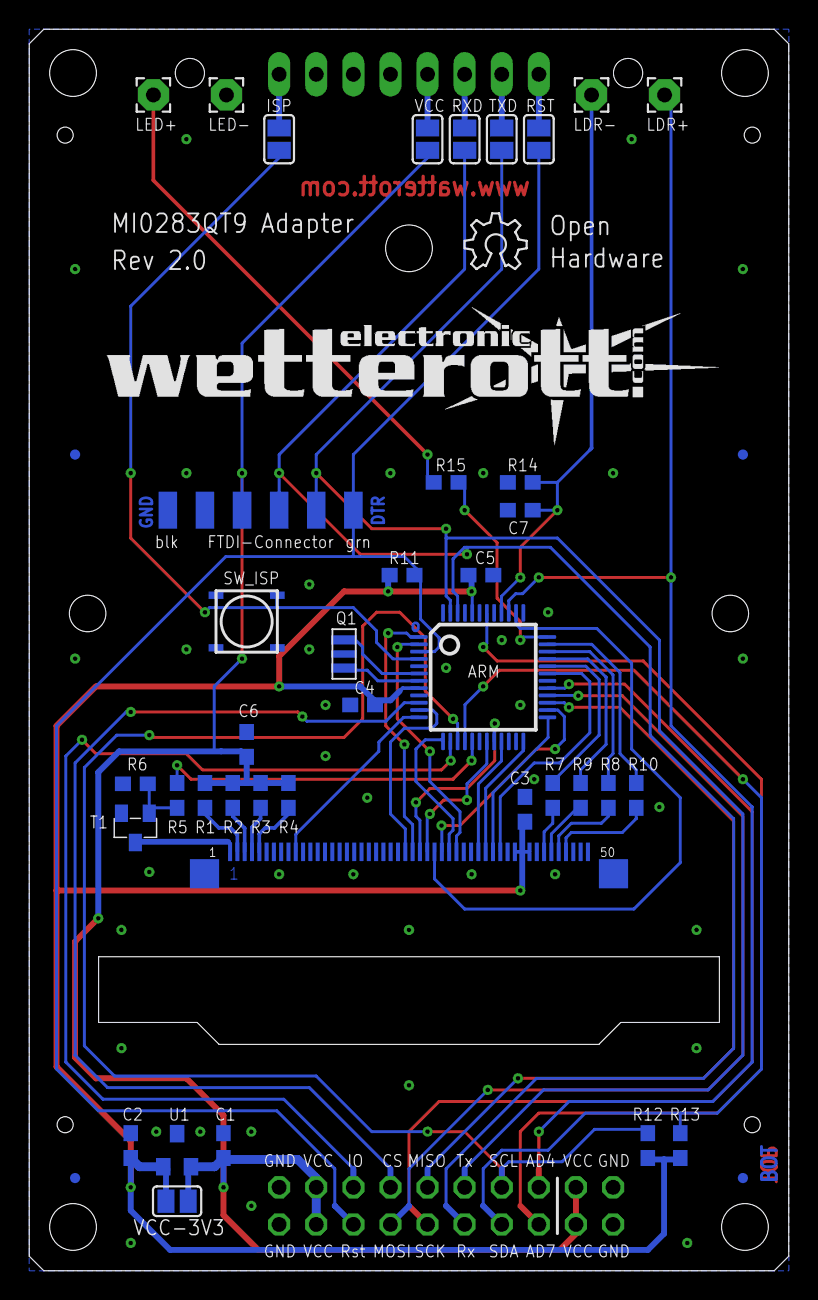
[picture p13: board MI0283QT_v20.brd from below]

Board: 2 copper layers, 52.0 x 85.0 mm, 52 parts (49 on the bottom side), 54 nets.

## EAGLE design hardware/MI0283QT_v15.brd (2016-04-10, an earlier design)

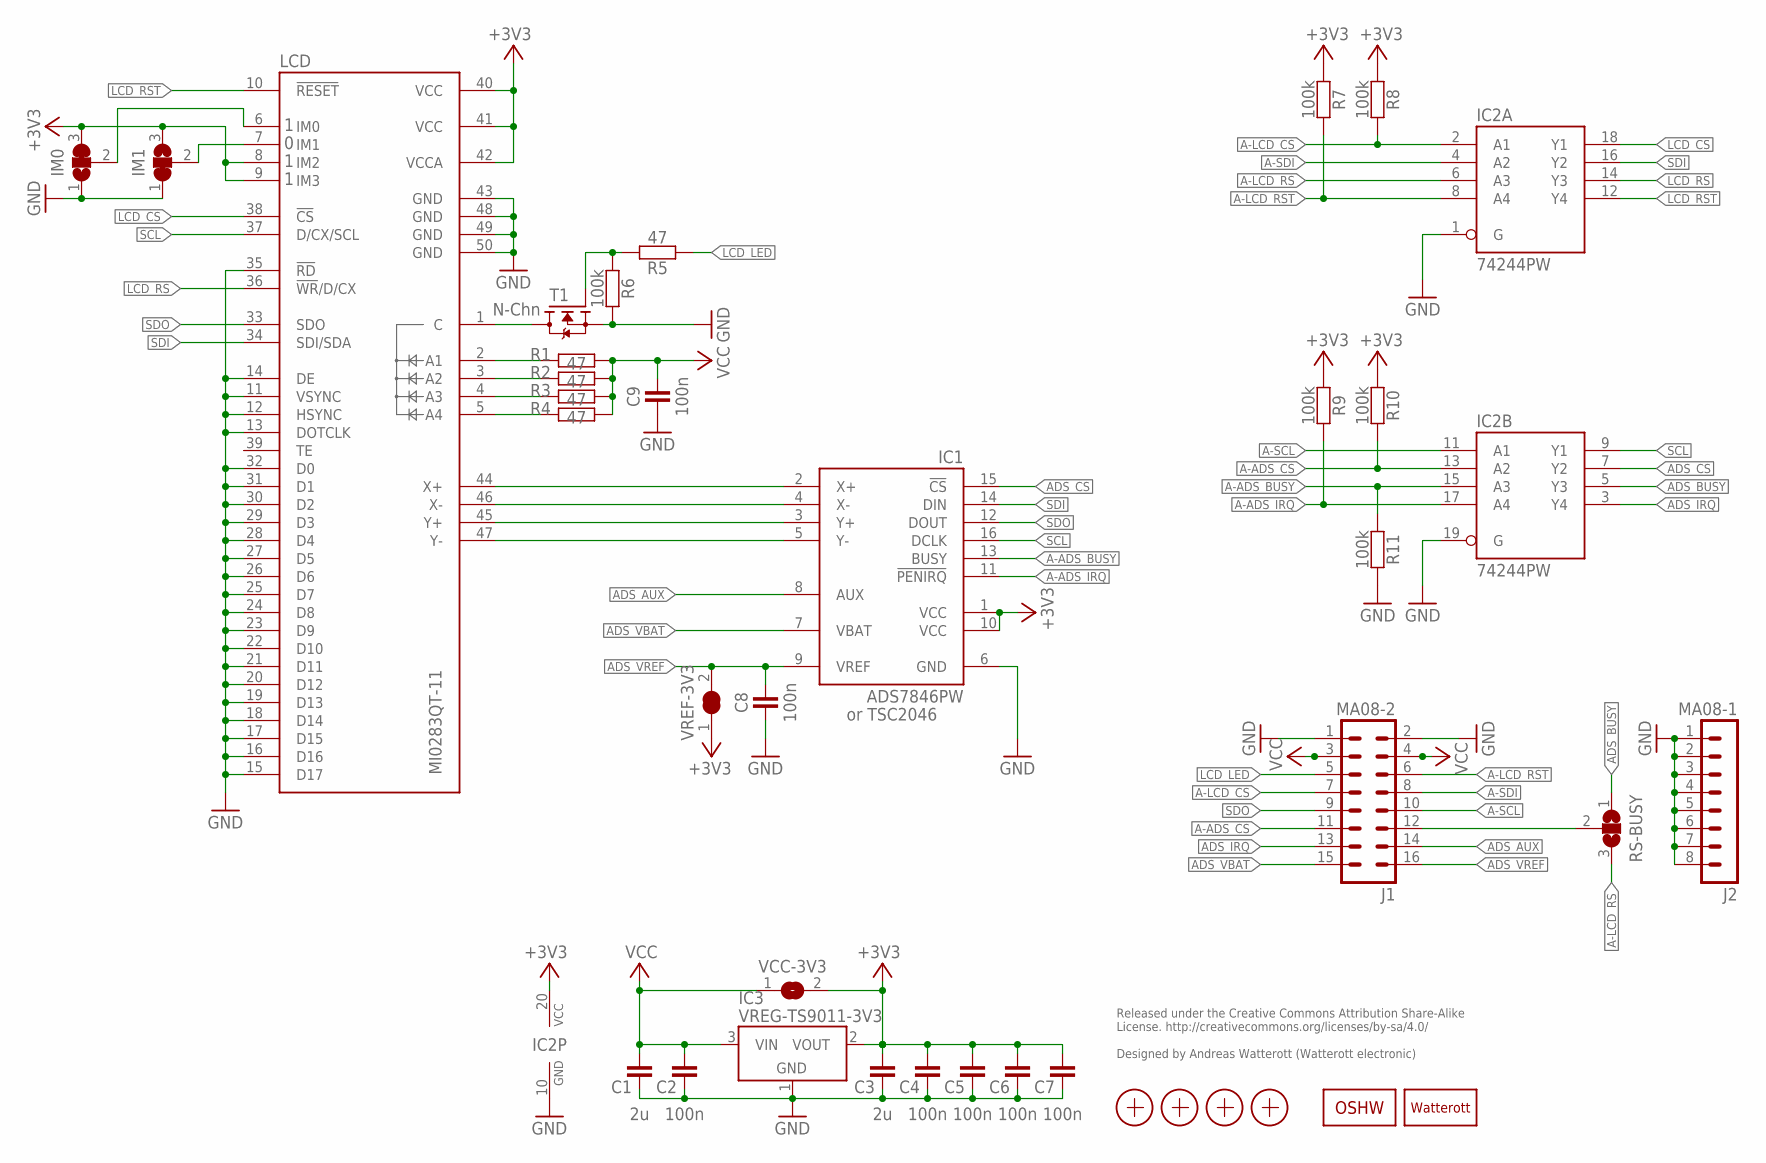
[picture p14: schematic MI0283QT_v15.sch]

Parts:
C1, C3: 2u; C0603
C2, C4, C5, C6, C7, C8, C9: 100n; C0402
IC1: ADS7846PW; TSSOP16
IC2: 74244PW; TSSOP20
IC3: VREG-TS9011-3V3; SOT23
IM0, IM1: JUMPER3-0603
J1: MA08-2
J2: MA08-1
LCD: MI0283QT-11; MI0283QT11
LOGO2: OSHW_LOGOX0150; OSHW_6X150
LOGO3: LOGO-PLACE; LOGO_TPLACE
R1, R2, R3, R4, R5: 47; C0402
R6, R7, R8, R9, R10, R11: 100k; C0402
RS-BUSY: JUMPER3-0603
T1: N-Chn; SOT23
VCC-3V3: JUMPER2-0603-NC; JUMPER2-0603_NC
VREF-3V3: JUMPER2-0603-NC; JUMPER2-0603_NC
X1, X2, X3, X4: PASSER-07; PASSER_07MM

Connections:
+3V3: C3.2, C4.2, C5.2, C6.2, C7.2, IC1.1 (VCC), IC1.10 (VCC), IC2.20 (VCC), IC3.2 (VOUT), IM0.3, IM1.3, LCD.8 (IM2), LCD.9 (IM3), LCD.40 (VCC), LCD.41 (VCC), LCD.42 (VCCA), R7.1, R8.1, R9.1, R10.1, VCC-3V3.2, VREF-3V3.1
A-ADS_BUSY: IC1.13 (BUSY), IC2.15 (A3), R11.1
A-ADS_CS: IC2.13 (A2), J1.11, R10.2
A-ADS_IRQ: IC1.11 (!PENIRQ), IC2.17 (A4), R9.2
A-LCD_CS: IC2.2 (A1), J1.7, R8.2
A-LCD_RS: IC2.6 (A3), RS-BUSY.3
A-LCD_RST: IC2.8 (A4), J1.6, R7.2
A-SCL: IC2.11 (A1), J1.10
A-SDI: IC2.4 (A2), J1.8
ADS_AUX: IC1.8 (AUX), J1.14
ADS_BUSY: IC2.5 (Y3), RS-BUSY.1
ADS_CS: IC1.15 (!CS), IC2.7 (Y2)
ADS_IRQ: IC2.3 (Y4), J1.13
ADS_VBAT: IC1.7 (VBAT), J1.15
ADS_VREF: C8.2, IC1.9 (VREF), J1.16, VREF-3V3.2
BUSY_RS: J1.12, RS-BUSY.2
C: LCD.1 (C), T1.3 (D)
GND: C1.1, C2.1, C3.1, C4.1, C5.1, C6.1, C7.1, C8.1, C9.1, IC1.6 (GND), IC2.1 (G), IC2.10 (GND), IC2.19 (G), IC3.1 (GND), IM0.1, IM1.1, J1.1, J1.2, J2.1, J2.2, J2.3, J2.4, J2.5, J2.6, J2.7, J2.8, LCD.11 (VSYNC), LCD.12 (HSYNC), LCD.13 (DOTCLK), LCD.14 (DE), LCD.15 (D17), LCD.16 (D16), LCD.17 (D15), LCD.18 (D14), LCD.19 (D13), LCD.20 (D12), LCD.21 (D11), LCD.22 (D10), LCD.23 (D9), LCD.24 (D8), LCD.25 (D7), LCD.26 (D6), LCD.27 (D5), LCD.28 (D4), LCD.29 (D3), LCD.30 (D2), LCD.31 (D1), LCD.32 (D0), LCD.35 (!RD), LCD.43 (GND), LCD.48 (GND), LCD.49 (GND), LCD.50 (GND), R6.2, R11.2, T1.2 (S)
IM0: IM0.2, LCD.6 (IM0)
LCD_CS: IC2.18 (Y1), LCD.38 (!CS)
LCD_LED: J1.5, R5.1
LCD_RS: IC2.14 (Y3), LCD.36 (!WR!/D/CX)
LCD_RST: IC2.12 (Y4), LCD.10 (!RESET)
LEDPWM: R5.2, R6.1, T1.1 (G)
LED_A1: LCD.2 (A1), R1.2
LED_A2: LCD.3 (A2), R2.2
LED_A3: LCD.4 (A3), R3.2
LED_A4: LCD.5 (A4), R4.2
unnamed: IC1.5 (Y-), LCD.47 (Y-)
unnamed: IC1.3 (Y+), LCD.45 (Y+)
unnamed: IC1.4 (X-), LCD.46 (X-)
unnamed: IC1.2 (X+), LCD.44 (X+)
unnamed: IM1.2, LCD.7 (IM1)
SCL: IC1.16 (DCLK), IC2.9 (Y1), LCD.37 (D/CX/SCL)
SDI: IC1.14 (DIN), IC2.16 (Y2), LCD.34 (SDI/SDA)
SDO: IC1.12 (DOUT), J1.9, LCD.33 (SDO)
VCC: C1.2, C2.2, C9.2, IC3.3 (VIN), J1.3, J1.4, R1.1, R2.1, R3.1, R4.1, VCC-3V3.1

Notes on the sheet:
Released under the Creative Commons Attribution Share-Alike License. http://creativecommons.org/licenses/by-sa/4.0/ Designed by Andreas Watterott (Watterott electronic)
or TSC2046

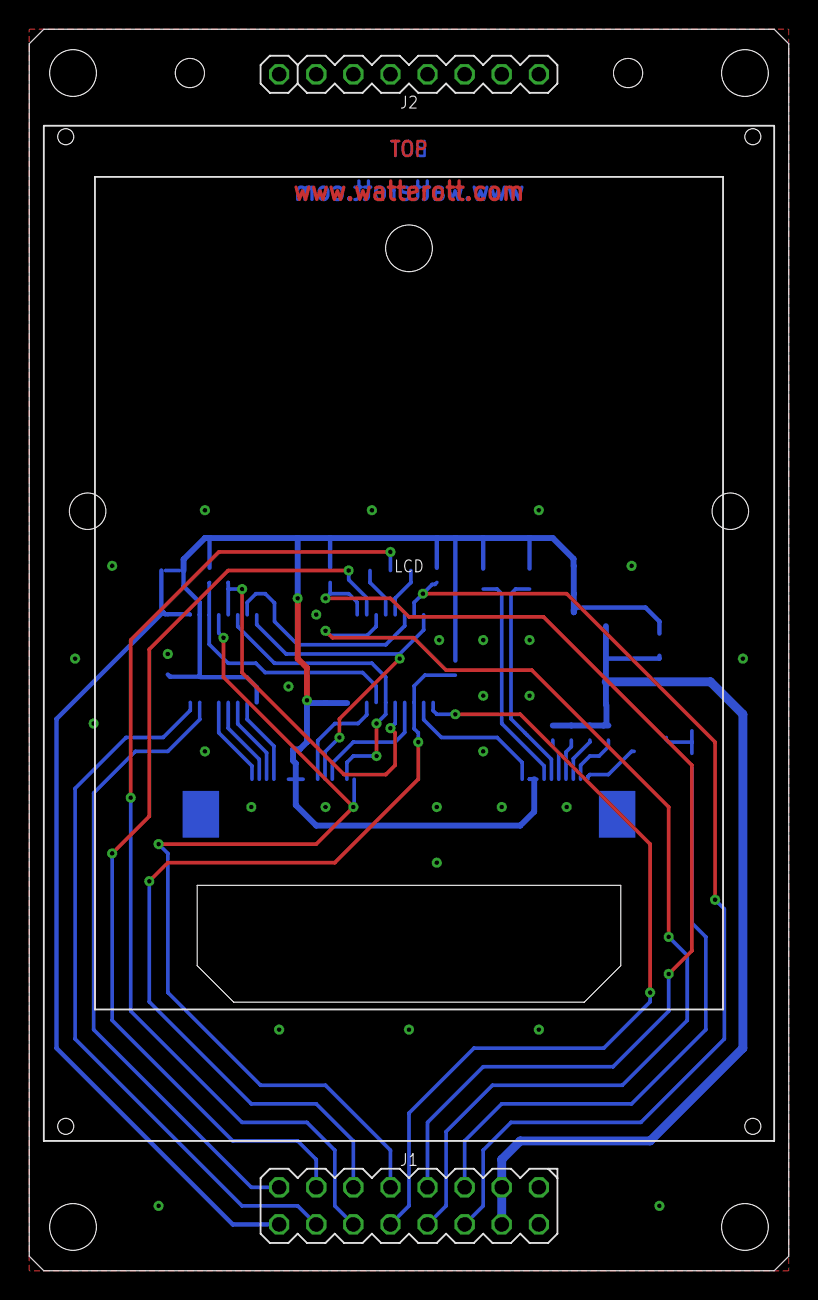
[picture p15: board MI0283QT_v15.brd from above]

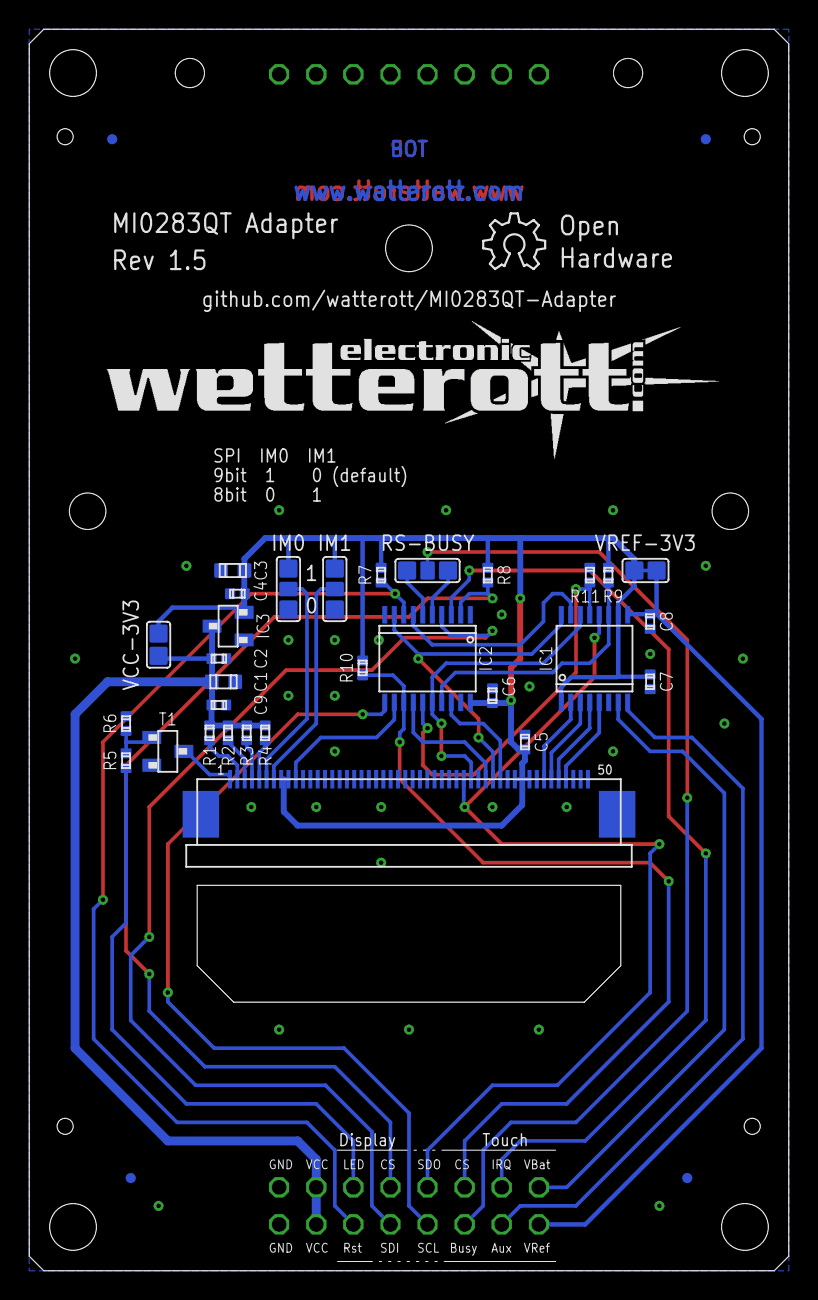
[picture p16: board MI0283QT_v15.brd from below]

Board: 2 copper layers, 52.0 x 85.0 mm, 38 parts (35 on the bottom side), 37 nets.

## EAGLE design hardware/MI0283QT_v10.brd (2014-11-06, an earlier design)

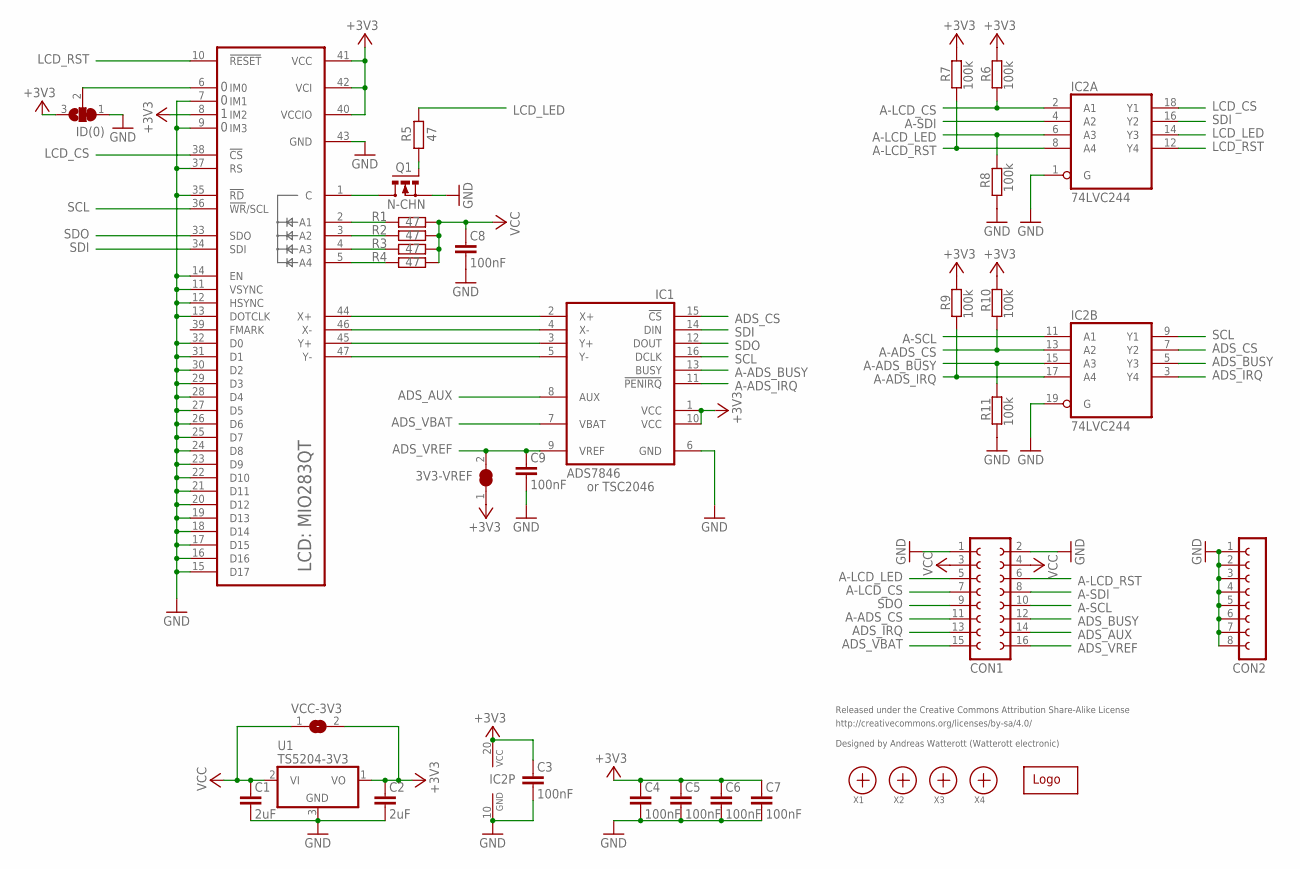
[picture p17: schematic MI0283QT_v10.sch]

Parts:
3V3-VREF: SJ
C1, C2: 2uF; C0805
C3, C4, C5, C6, C7, C8, C9: 100nF; C0603
CON1: FE08-2
CON2: FE08-1; FE08
IC1: ADS7846; SSOP16
IC2: 74LVC244; SO20W
ID(0): SJ2W; SJ_2
LCD: MI0283QT
Q1: N-CHN; MICRO3
R1, R2, R3, R4, R5: 47; R0603
R6, R7, R8, R9, R10, R11: 100k; R0603
U1: TS5204-3V3; SOT23
U$1: WE-LOGO
VCC-3V3: SJ
X1, X2, X3, X4: PASSER

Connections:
+3V3: 3V3-VREF.1, C2.1, C3.1, C4.1, C5.1, C6.1, C7.1, IC1.1 (VCC), IC1.10 (VCC), IC2.20 (VCC), ID(0).3, LCD.8 (IM2), LCD.40 (VCCIO), LCD.41 (VCC), LCD.42 (VCI), R6.2, R7.2, R9.2, R10.2, U1.1 (VO), VCC-3V3.2
A-ADS_BUSY: IC1.13 (BUSY), IC2.15 (A3), R11.1
A-ADS_CS: CON1.11, IC2.13 (A2), R10.1
A-ADS_IRQ: IC1.11 (!PENIRQ), IC2.17 (A4), R9.1
A-LCD_CS: CON1.7, IC2.2 (A1), R6.1
A-LCD_LED: CON1.5, IC2.6 (A3), R8.1
A-LCD_RST: CON1.6, IC2.8 (A4), R7.1
A-SCL: CON1.10, IC2.11 (A1)
A-SDI: CON1.8, IC2.4 (A2)
ADS_AUX: CON1.14, IC1.8 (AUX)
ADS_BUSY: CON1.12, IC2.5 (Y3)
ADS_CS: IC1.15 (!CS), IC2.7 (Y2)
ADS_IRQ: CON1.13, IC2.3 (Y4)
ADS_VBAT: CON1.15, IC1.7 (VBAT)
ADS_VREF: 3V3-VREF.2, C9.1, CON1.16, IC1.9 (VREF)
C: LCD.1 (C), Q1.3 (D)
GND: C1.2, C2.2, C3.2, C4.2, C5.2, C6.2, C7.2, C8.2, C9.2, CON1.1, CON1.2, CON2.1, CON2.2, CON2.3, CON2.4, CON2.5, CON2.6, CON2.7, CON2.8, IC1.6 (GND), IC2.1 (G), IC2.10 (GND), IC2.19 (G), ID(0).1, LCD.7 (IM1), LCD.9 (IM3), LCD.11 (VSYNC), LCD.12 (HSYNC), LCD.13 (DOTCLK), LCD.14 (EN), LCD.15 (D17), LCD.16 (D16), LCD.17 (D15), LCD.18 (D14), LCD.19 (D13), LCD.20 (D12), LCD.21 (D11), LCD.22 (D10), LCD.23 (D9), LCD.24 (D8), LCD.25 (D7), LCD.26 (D6), LCD.27 (D5), LCD.28 (D4), LCD.29 (D3), LCD.30 (D2), LCD.31 (D1), LCD.32 (D0), LCD.35 (!RD), LCD.37 (RS), LCD.43 (GND), Q1.2 (S), R8.2, R11.2, U1.3 (GND)
IM0: ID(0).2, LCD.6 (IM0)
LCD_CS: IC2.18 (Y1), LCD.38 (!CS)
LCD_LED: IC2.14 (Y3), R5.2
LCD_RST: IC2.12 (Y4), LCD.10 (!RESET)
LEDPWM: Q1.1 (G), R5.1
LED_A1: LCD.2 (A1), R1.1
LED_A2: LCD.3 (A2), R2.1
LED_A3: LCD.4 (A3), R3.1
LED_A4: LCD.5 (A4), R4.1
SCL: IC1.16 (DCLK), IC2.9 (Y1), LCD.36 (!WR!/SCL)
SDI: IC1.14 (DIN), IC2.16 (Y2), LCD.34 (SDI)
SDO: CON1.9, IC1.12 (DOUT), LCD.33 (SDO)
VCC: C1.1, C8.1, CON1.3, CON1.4, R1.2, R2.2, R3.2, R4.2, U1.2 (VI), VCC-3V3.1
X+: IC1.2 (X+), LCD.44 (X+)
X-: IC1.4 (X-), LCD.46 (X-)
Y+: IC1.3 (Y+), LCD.45 (Y+)
Y-: IC1.5 (Y-), LCD.47 (Y-)

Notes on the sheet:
Released under the Creative Commons Attribution Share-Alike License
http://creativecommons.org/licenses/by-sa/4.0/
Designed by Andreas Watterott (Watterott electronic)
or TSC2046

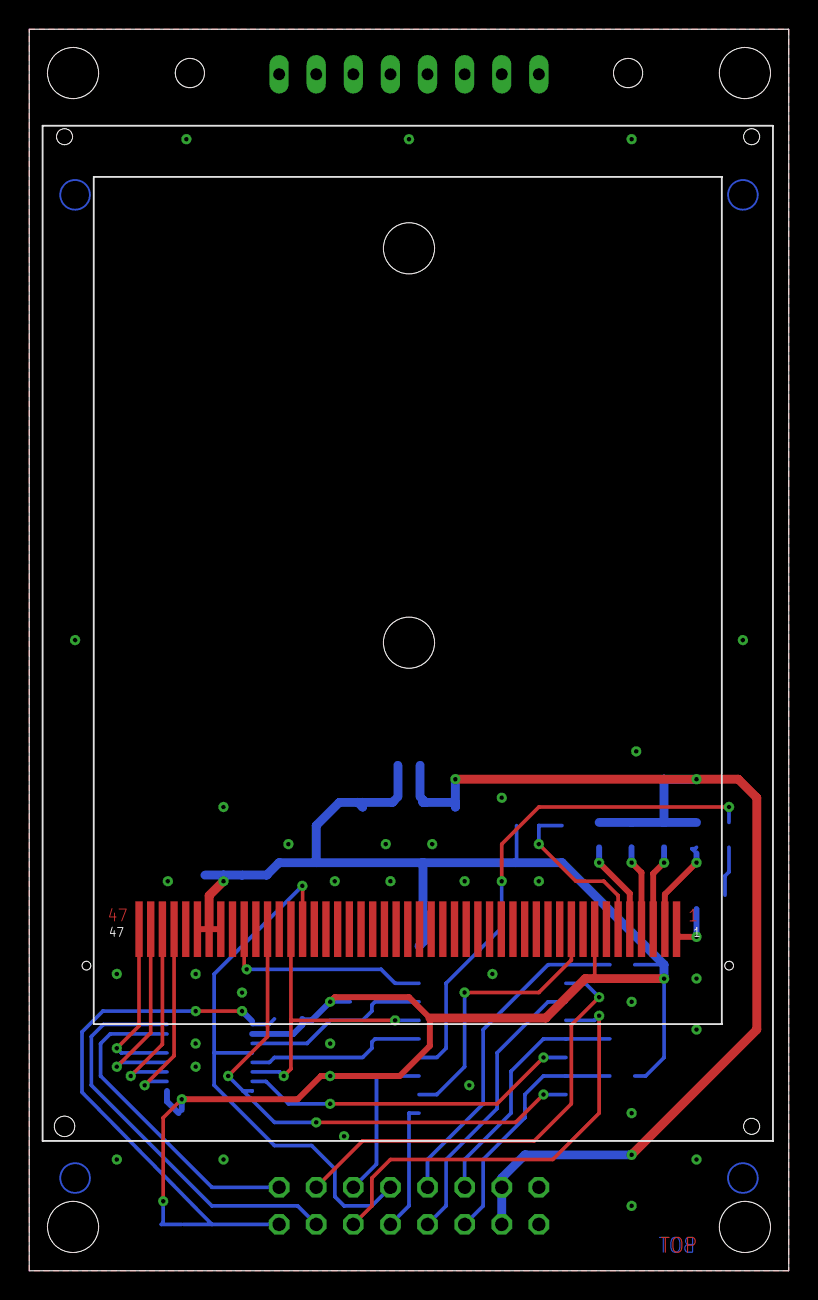
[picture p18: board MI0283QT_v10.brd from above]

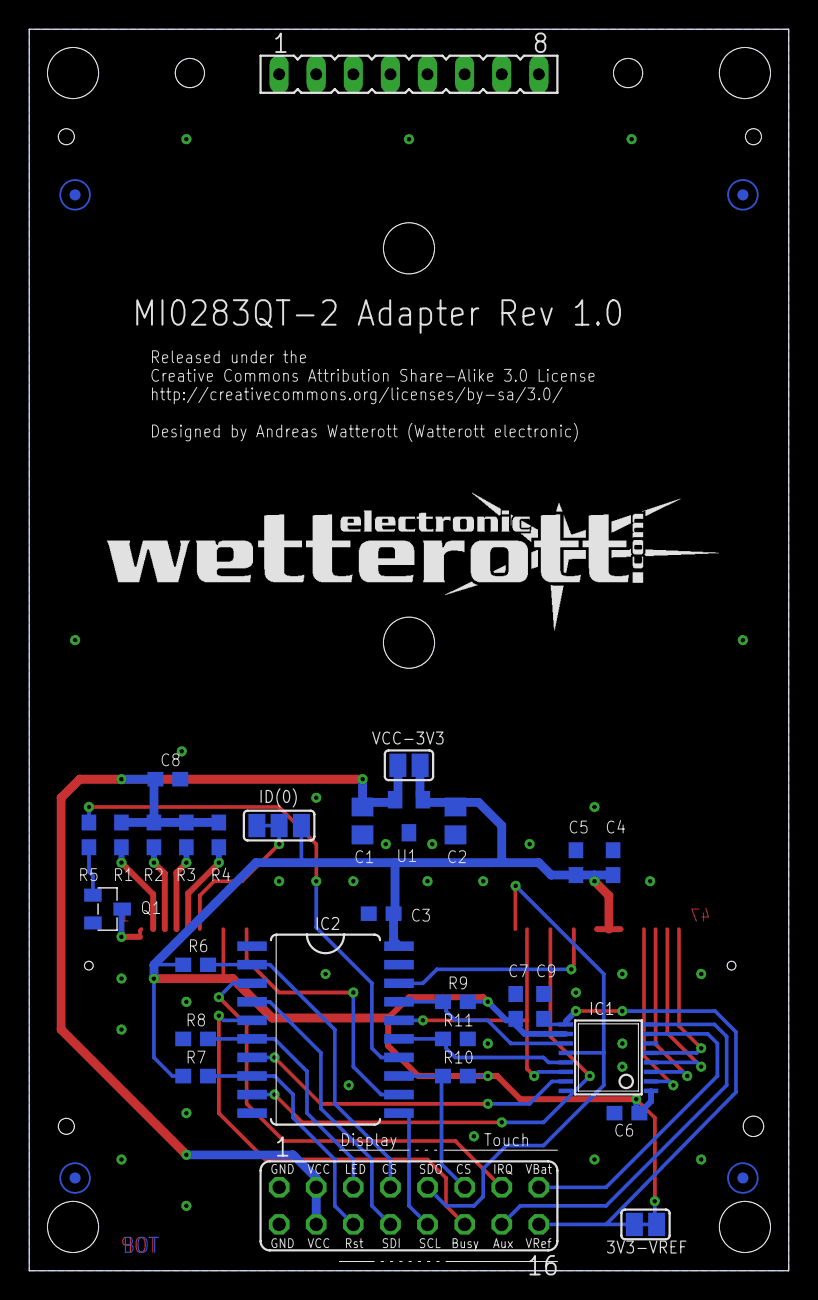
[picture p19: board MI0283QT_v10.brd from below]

Board: 2 copper layers, 52.0 x 85.0 mm, 35 parts (34 on the bottom side), 34 nets.

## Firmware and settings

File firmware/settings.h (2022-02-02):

#ifndef _SETTINGS_H_
#define _SETTINGS_H_


//----- DEFINES -----
#define VERSION         "0.08"

//LCD support (define only one)
#define LCD_MI0283QT9 //MI0283QT-9/-11 (ILI9341)
//#define LCD_UG12D228AA

#ifdef LCD_MI0283QT9
#define TP_SUPPORT //resistive touch panel support
#endif

#define DEFAULT_CLOCK   48000000UL    //Hz, 12 16* 24 32* 36 48* MHz (*crystal)
#define DEFAULT_POWER   0             //0-100 power for backlight
#define DEFAULT_LDRTIME 500           //check LDR every 500 milliseconds
#define DEFAULT_INTERF  INTERFACE_I2C //INTERFACE_I2C INTERFACE_SPI INTERFACE_UART
#define DEFAULT_BAUD    9600          //UART baud rate
#define DEFAULT_ADDR    0x20          //I2C address
#define DEFAULT_ORDER   0             //byte order (0=big, 1=little)


//----- PINS -----
//GPIO
#define IO_PORT         0
#define IO_PIN          3
//ext. LED
#define LED_PORT        3
#define LED_PIN         0
//PWM for backlight
#define PWM_PORT        1
#define PWM_PIN         9 //CT16B1MAT0
//Rotary Encoder
#define ENC_PORT        1
#define ENC_SW          2
#define ENC_A           1
#define ENC_B           0
//Navigation Switch
#define NAV_PORT        1
#define NAV_SW          2
#define NAV_A           0
#define NAV_B           1
#define NAV_C           4
#define NAV_D           3
//ADC
#define ADC_PORT        1
#define ADC_4           3  //R_PIO1_3 = AD4
#define ADC_5           4  //PIO1_4 = AD5
#define ADC_7           11 //PIO1_11 = AD11
//Interface
#define SS_PORT         0
#define SS_PIN          2
#define I2C_PORT        0
#define SCL_PIN         4
#define SDA_PIN         5
#define SPI_PORT        0
#define MISO_PIN        8
#define MOSI_PIN        9
#define SCK_PIN         10
#define UART_PORT       1
#define RX_PIN          6
#define TX_PIN          7
//Touch-Panel
#define XP_PORT         0
#define XP_PIN          11 //R_PIO0_11 = AD0
#define XP_AD           0
#define XM_PORT         1
#define XM_PIN          1  //R_PIO1_1 = AD2
#define XM_AD           2
#define YP_PORT         1
#define YP_PIN          0  //R_PIO1_0 = AD1
#define YP_AD           1
#define YM_PORT         1
#define YM_PIN          2  //R_PIO1_2 = AD3
#define YM_AD           3


//----- GLOBAL MACROS -----
#define NOP()                          __asm__ volatile ("nop")
#define ENABLE_IRQ()                   __asm__ volatile ("cpsie i")
#define DISABLE_IRQ()                  __asm__ volatile ("cpsid i")

#define CONCATx(a, b)                  a##b
#define CONCATx3(a, b, c)              a##b##c
#define CONCATx4(a, b, c, d)           a##b##c##d
#define CONCAT(a, b)                   CONCATx(a, b)
#define CONCAT3(a, b, c)               CONCATx3(a, b, c)
#define CONCAT4(a, b, c, d)            CONCATx4(a, b, c, d)

#define GPIO_PORT(port)                CONCAT(LPC_GPIO, port)
#define GPIO_SETPIN(port, pin)         CONCAT(LPC_GPIO, port)->MASKED_ACCESS[(1<<pin)] = (1<<pin)
#define GPIO_CLRPIN(port, pin)         CONCAT(LPC_GPIO, port)->MASKED_ACCESS[(1<<pin)] = 0
#define GPIO_SETPORT(port, pins, val)  CONCAT(LPC_GPIO, port)->MASKED_ACCESS[pins] = val
#define GPIO_GETPIN(port, pin)         CONCAT(LPC_GPIO, port)->MASKED_ACCESS[(1<<pin)]
#define GPIO_GETPORT(port, pins)       CONCAT(LPC_GPIO, port)->MASKED_ACCESS[pins]

#define IOCON_PIO                      (0x00<<0) //pio
#define IOCON_R_PIO                    (0x01<<0) //pio (reserved pins)
#define IOCON_ADC                      (0x01<<0) //adc
#define IOCON_R_ADC                    (0x02<<0) //adc (reserved pins)
#define IOCON_NOPULL                   (0x00<<3) //no pull-down/pull-up
#define IOCON_PULLDOWN                 (0x01<<3) //pull-down
#define IOCON_PULLUP                   (0x02<<3) //pull-up
#define IOCON_ANALOG                   (0x00<<7) //analog (adc pins)
#define IOCON_DIGITAL                  (0x01<<7) //digital (adc pins)
#define IOCON_SETRPIN(port, pin, val)  LPC_IOCON->CONCAT4(R_PIO, port, _, pin) = val
#define IOCON_SETPIN(port, pin, val)   LPC_IOCON->CONCAT4(PIO, port, _, pin) = val

#define ADC_READ(chn, x)             { LPC_ADC->CR |= (1<<chn);              \
                                       LPC_ADC->CR |= (1<<24);               \
                                       while(!(LPC_ADC->DR[chn] & (1<<31))); \
                                       LPC_ADC->CR &= 0xF8FFFF00;            \
                                       x = ((LPC_ADC->DR[chn]>>6) & 0x3FF);  }


#endif //_SETTINGS_H_

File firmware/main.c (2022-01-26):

#include <stdint.h>
#include <stdlib.h>
#include <stdio.h>
#include "cmsis/LPC11xx.h"
#include "settings.h"
#include "main.h"
#include "iap.h"
#include "cmd.h"
#include "interface.h"
#include "lcd_mi0283qt9.h"
#include "lcd_ug12d228aa.h"
#include "lcd.h"
#include "lcd_font8x8.h"
#include "tp.h"


//set read/write byte count for position data
#if ((LCD_WIDTH > 255) || (LCD_HEIGHT > 255))
# define if_read  if_read16
# define if_write if_write16
#else
# define if_read  if_read8
# define if_write if_write8
#endif


uint32_t global_buffer[FLASH_SECTOR_BYTES/4]; //see iap.h
volatile uint_least32_t ms_ticks=0;
volatile uint_least8_t features=0, status=0, io_config=0;
volatile uint_least8_t enc_sw=0;
volatile int_least8_t enc_delta=0;
uint_least8_t enc_last=0;
volatile uint_least8_t nav_sw=0;
volatile int_least8_t nav_hdelta=0, nav_vdelta=0; //h=left-right, v=up-down
uint_least32_t nav_last=0;

typedef struct
{
  uint32_t magic; //0xDEADBEEF
  uint8_t sysclock;
  uint8_t power;
  uint8_t interface;
  uint32_t baudrate;
  uint8_t address;
  uint8_t byteorder;
  uint16_t fgcolor;
  uint16_t bgcolor;
  CAL_MATRIX tp;
  uint32_t padding;
} SETTINGS;
SETTINGS *usersettings = (SETTINGS*)(FLASH_BYTES-128); //last 128 bytes are for settings


void SysTick_Handler(void) //runs every 1ms
{
  ms_ticks++;

#ifndef TP_SUPPORT

  static uint_least8_t enc_t=0, enc_sw_t=0;
  static uint_least8_t nav_t=0, nav_sw_t=0, inc_h=0, inc_v=0;
  uint_least32_t pin, p;
  uint_least8_t n, dif;

  if(features & FEATURE_ENC)
  {
    if(++enc_t == 5) //every 5ms
    {
      enc_t = 0;

      //get pin state
      pin = GPIO_GETPORT(ENC_PORT, (1<<ENC_SW)|(1<<ENC_A)|(1<<ENC_B));
 
      //check encoder phases
      n = 0;
      if(pin & (1<<ENC_A))
      {
        n = 3;
      }
      if(pin & (1<<ENC_B))
      {
        n ^= 1; //convert gray to binary
      }
      dif = enc_last - n; //difference last - new
      if(dif & 1) //bit 0 = value (1)
      {               
        enc_last = n; //store new as next last
        enc_delta += (dif & 2) - 1; //bit 1 = direction (+/-)
      }

      //check encoder switch
      if((pin & (1<<ENC_SW)) == 0)
      {
        enc_sw_t++;
        if(enc_sw_t >= (1000/5)) //1000ms
        {
          enc_sw |= 0x02;
        }
        if(enc_sw_t >= (100/5)) //100ms
        {
          enc_sw |= 0x01;
        }
      }
      else
      {
        enc_sw_t = 0;
      }
    }
  }

  if(features & FEATURE_NAV)
  {
    if(++nav_t == 25) //every 25ms
    {
      nav_t = 0;

      //get pin state
      p        = GPIO_GETPORT(NAV_PORT, (1<<NAV_SW)|(1<<NAV_A)|(1<<NAV_B)|(1<<NAV_C)|(1<<NAV_D));
      pin      = p & nav_last;
      nav_last = p;

      //check nav switches
      if((pin & (1<<NAV_C)) == 0) //right
      {
        nav_sw |= 0x10;
        nav_hdelta += inc_h;
        inc_h = 0;
      }
      else if((pin & (1<<NAV_A)) == 0) //left
      {
        nav_sw |= 0x20;
        nav_hdelta -= inc_h;
        inc_h = 0;
      }
      else
      {
        inc_h = 1;
      }

      if((pin & (1<<NAV_D)) == 0) //up
      {
        nav_sw |= 0x40;
        nav_vdelta += inc_v;
        inc_v = 0;
      }
      else if((pin & (1<<NAV_B)) == 0) //down
      {
        nav_sw |= 0x80;
        nav_vdelta -= inc_v;
        inc_v = 0;
      }
      else
      {
        inc_v = 1;
      }

      if((pin & (1<<NAV_SW)) == 0)
      {
        nav_sw_t++;
        if(nav_sw_t >= (1000/25)) //long press: 1000ms
        {
          nav_sw |= 0x02;
        }
        if(nav_sw_t >= (100/25)) //short press: 100ms
        {
          nav_sw |= 0x01;
        }
      }
      else
      {
        nav_sw_t = 0;
      }
    }
  }

#endif

  return;
}


//Rotary Encoder routine by Peter Dannegger
//http://www.mikrocontroller.net/articles/Drehgeber

int_least8_t enc_getdelta(void)
{
  int_least8_t val;

  DISABLE_IRQ();

  val = enc_delta;

  //read single step encoders
  // enc_delta = 0;
  //read two step encoders
  // enc_delta = val & 1;
  // val >>= 1;
  //read four step encoders
  enc_delta = val & 3;
  val >>= 2;

  ENABLE_IRQ();

  return val;
}


uint_least8_t enc_getsw(void)
{
  uint_least8_t sw;

  sw = enc_sw;
  enc_sw = 0;

  return sw;
}


void enc_init(void)
{
  //GPIO_PORT(ENC_PORT)->DIR &= (1<<ENC_SW)|(1<<ENC_A)|(1<<ENC_B);
  IOCON_SETRPIN(ENC_PORT, ENC_SW, IOCON_R_PIO | IOCON_PULLUP | IOCON_DIGITAL); //GPIO with pull-up
  IOCON_SETRPIN(ENC_PORT, ENC_A,  IOCON_R_PIO | IOCON_PULLUP | IOCON_DIGITAL); //GPIO with pull-up
  IOCON_SETRPIN(ENC_PORT, ENC_B,  IOCON_R_PIO | IOCON_PULLUP | IOCON_DIGITAL); //GPIO with pull-up

  if(GPIO_GETPIN(ENC_PORT, ENC_A))
  {
    enc_last = 3;
  }
  if(GPIO_GETPIN(ENC_PORT, ENC_B))
  {
    enc_last ^= 1; //convert gray to binary
  }
  enc_delta = 0;
  enc_sw = 0;

  return;
}


int_least8_t nav_gethdelta(void)
{
  int_least8_t val;

  val = nav_hdelta;
  nav_hdelta = 0;

  return val;
}


int_least8_t nav_getvdelta(void)
{
  int_least8_t val;

  val = nav_vdelta;
  nav_vdelta = 0;

  return val;
}


uint_least8_t nav_getsw(void)
{
  uint_least8_t sw;

  sw = nav_sw;
  nav_sw = 0;

  return sw;
}


void nav_init(void)
{
  //GPIO_PORT(NAV_PORT)->DIR &= (1<<NAV_SW)|(1<<NAV_A)|(1<<NAV_B)|(1<<NAV_C)|(1<<NAV_D);
  IOCON_SETRPIN(NAV_PORT, NAV_SW, IOCON_R_PIO | IOCON_PULLUP | IOCON_DIGITAL); //GPIO with pull-up
  IOCON_SETRPIN(NAV_PORT, NAV_A,  IOCON_R_PIO | IOCON_PULLUP | IOCON_DIGITAL); //GPIO with pull-up
  IOCON_SETRPIN(NAV_PORT, NAV_B,  IOCON_R_PIO | IOCON_PULLUP | IOCON_DIGITAL); //GPIO with pull-up
  IOCON_SETPIN(NAV_PORT,  NAV_C,  IOCON_PIO   | IOCON_PULLUP | IOCON_DIGITAL); //GPIO with pull-up
  IOCON_SETRPIN(NAV_PORT, NAV_D,  IOCON_R_PIO | IOCON_PULLUP | IOCON_DIGITAL); //GPIO with pull-up

  nav_sw = 0;
  nav_hdelta = 0;
  nav_vdelta = 0;
  nav_last = 0;

  return;
}


uint_least8_t ldr_service(uint_least8_t power_max)
{
  uint_least16_t i, j;
  static uint_least8_t last=0;

  //set AD4 to high
  GPIO_SETPIN(ADC_PORT, ADC_4);

  //read AD5
  //IOCON_SETPIN(ADC_PORT, ADC_5, IOCON_ADC | IOCON_NOPULL | IOCON_ANALOG);
  ADC_READ(5, i);
  ADC_READ(5, j);
  //IOCON_SETPIN(ADC_PORT, ADC_5, IOCON_PIO | IOCON_NOPULL | IOCON_DIGITAL);

  //set AD4 to low
  GPIO_CLRPIN(ADC_PORT, ADC_4);

  if(i == j)
  {
         if(i > 800) i = 100;
    else if(i > 100) i /= 8;
    else             i = 10;
    last += i; //add current to last value
    last /= 2; //div by 2 (do average)
    if(last > power_max)
    {
      last = power_max;
    }
    set_pwm(last);
  }
  else if(last == 0)
  {
    last = power_max;
    set_pwm(last);
  }

  return last;
}


void ldr_init(void)
{
  //set AD4 to output and low
  IOCON_SETRPIN(ADC_PORT, ADC_4, IOCON_R_PIO | IOCON_NOPULL | IOCON_DIGITAL);
  GPIO_CLRPIN(ADC_PORT, ADC_4);
  GPIO_PORT(ADC_PORT)->DIR |= (1<<ADC_4);

  //set AD5 to analog
  IOCON_SETPIN(ADC_PORT, ADC_5, IOCON_ADC | IOCON_NOPULL | IOCON_ANALOG);

  return;
}


uint_least16_t adc_read(uint_least8_t chn)
{
  uint_least16_t i=0;

  switch(chn)
  {
    case 4:
      IOCON_SETRPIN(ADC_PORT, ADC_4, IOCON_R_ADC | IOCON_NOPULL | IOCON_ANALOG);
      ADC_READ(4, i);
      IOCON_SETRPIN(ADC_PORT, ADC_4, IOCON_R_PIO | IOCON_PULLUP | IOCON_DIGITAL);
      break;
    case 5:
      IOCON_SETPIN(ADC_PORT, ADC_5, IOCON_ADC | IOCON_NOPULL | IOCON_ANALOG);
      ADC_READ(5, i);
      IOCON_SETPIN(ADC_PORT, ADC_5, IOCON_PIO | IOCON_PULLUP | IOCON_DIGITAL);
      break;
    case 7:
      IOCON_SETPIN(ADC_PORT, ADC_7, IOCON_ADC | IOCON_NOPULL | IOCON_ANALOG);
      ADC_READ(7, i);
      IOCON_SETPIN(ADC_PORT, ADC_7, IOCON_PIO | IOCON_PULLUP | IOCON_DIGITAL);
      break;
    case 255:
      //set AD4 to output and high
      IOCON_SETRPIN(ADC_PORT, ADC_4, IOCON_R_PIO | IOCON_NOPULL | IOCON_DIGITAL);
      GPIO_SETPIN(ADC_PORT, ADC_4);
      GPIO_PORT(ADC_PORT)->DIR |= (1<<ADC_4);
      //read AD5
      IOCON_SETPIN(ADC_PORT, ADC_5, IOCON_ADC | IOCON_NOPULL | IOCON_ANALOG);
      ADC_READ(5, i);
      IOCON_SETPIN(ADC_PORT, ADC_5, IOCON_PIO | IOCON_NOPULL | IOCON_DIGITAL);
      //set AD4 to low
      GPIO_CLRPIN(ADC_PORT, ADC_4);
      break;
  }

  return i;
}


void io_set(uint_least8_t source)
{
  status |= source;

  if(features & FEATURE_IRQ)
  {
    if(io_config == 0)
    {
       GPIO_CLRPIN(IO_PORT, IO_PIN);
    }
    else
    {
       GPIO_SETPIN(IO_PORT, IO_PIN);
    }
  }

  return;
}


void io_clr(uint_least8_t source)
{
  status &= ~source;

  if(features & FEATURE_IRQ)
  {
    if(io_config == 0)
    {
       GPIO_SETPIN(IO_PORT, IO_PIN);
    }
    else
    {
       GPIO_CLRPIN(IO_PORT, IO_PIN);
    }
  }

  return;
}


uint_least32_t get_ms(void)
{
  return ms_ticks;
}


void delay_ms(uint_least32_t delay)
{
  uint_least32_t current = get_ms();

  while((get_ms() - current) < delay);

  return;
}


void delay(uint_least32_t delay)
{
  for( ; delay!=0; delay--)
  {
    NOP();
  }

  return;
}


uint_least8_t set_pwm(uint_least8_t power)
{
  if(power == 0)
  {
    LPC_IOCON->PIO1_9 = (0x0<<0); //PIO1_9/CT16B1MAT0 -> GPIO
    LPC_TMR16B1->TCR  = (0<<0); //disable timer
    return power;
  }
  else if(power > 100)
  {
    power = 100;
  }

  LPC_IOCON->PIO1_9 = (0x1<<0); //PIO1_9/CT16B1MAT0 -> PWM
  LPC_TMR16B1->TCR  = (1<<0); //enable timer
  LPC_TMR16B1->MR0  = ~((0xFFFF*power)/100);

  return power;
}


uint_least32_t sysclock(uint_least32_t clock)
{
  static uint_least32_t current_clock=12000000UL;
  uint_least32_t i, pllclksel=0, pllctrl=0;

  //get clock
  if(clock == 0)
  {
    return current_clock;
  }

  //set clock
  //Fclkout = M * Fclkin = FCCO / (2 * P)
  //FCCO = 2 * P * Fclkout
  //  Fclkin  Fclkout  MSEL   Mdiv PSEL Pdiv FCCO
  //  12 MHz  24 MHz   00001  2    10   4    192 MHz
  //  12 MHz  36 MHz   00010  3    10   4    288 MHz
  //  12 MHz  48 MHz   00011  4    01   2    192 MHz
  //  16 MHz  32 MHz   00001  2    10   4    256 MHz
  //  16 MHz  48 MHz   00010  3    01   2    192 MHz
  switch(clock)
  {
    default:
    case 12000000UL:
      current_clock = clock;
      pllclksel = (0x0<<0); //IRC osc
      pllctrl   = 0;
      break;
    case 16000000UL:
      current_clock = clock;
      pllclksel = (0x1<<0); //SYS osc
      pllctrl   = 0;
      break;
    case 24000000UL:
      current_clock = clock;
      pllclksel = (0x0<<0); //IRC osc
      pllctrl   = (0x1<<0) | (0x2<<5);
      break;
    case 32000000UL:
      current_clock = clock;
      pllclksel = (0x1<<0); //SYS osc
      pllctrl   = (0x1<<0) | (0x2<<5);
      break;
    case 36000000UL:
      current_clock = clock;
      pllclksel = (0x0<<0); //IRC osc
      pllctrl   = (0x2<<0) | (0x2<<5);
      break;
    case 48000000UL:
      current_clock = clock;
      pllclksel = (0x1<<0); //SYS osc
      pllctrl   = (0x2<<0) | (0x1<<5);
      break;
  }

  DISABLE_IRQ();

  if(pllclksel != 0) //SYS osc
  {
    LPC_SYSCON->PDRUNCFG &= ~(1<<5); //enable SYS osc
    LPC_SYSCON->SYSOSCCTRL = (0<<0); //0-20MHz
  }
  else //IRC osc
  {
    LPC_SYSCON->PDRUNCFG &= ~((1<<0)|(1<<1)); //enable IRC osc
  }
  for(i=0; i<200; i++){ NOP(); }
  LPC_SYSCON->SYSPLLCLKSEL = pllclksel;
  LPC_SYSCON->SYSPLLCLKUEN = (1<<0); //update clock source
  LPC_SYSCON->SYSPLLCLKUEN = (0<<0); //toggle update register
  LPC_SYSCON->SYSPLLCLKUEN = (1<<0); //update clock source again
  while(!(LPC_SYSCON->SYSPLLCLKUEN & (1<<0))); //wait until updated

  if(pllctrl != 0) // PLL on
  {
    LPC_SYSCON->SYSPLLCTRL = pllctrl;
    LPC_SYSCON->PDRUNCFG &= ~(1<<7); //enable PLL
    while(!(LPC_SYSCON->SYSPLLSTAT & (1<<0))); //wait for PLL to lock
    LPC_SYSCON->MAINCLKSEL = (0x3<<0); //select PLL
    LPC_SYSCON->MAINCLKUEN = (1<<0); //update clock source
    LPC_SYSCON->MAINCLKUEN = (0<<0); //toggle update reg
    LPC_SYSCON->MAINCLKUEN = (1<<0); //update clock source again
    while(!(LPC_SYSCON->MAINCLKUEN & (1<<0))); //wait until updated
  }
  else
  {
    LPC_SYSCON->MAINCLKSEL = pllclksel; //select IRC osc
    LPC_SYSCON->MAINCLKUEN = (1<<0); //update clock source
    LPC_SYSCON->MAINCLKUEN = (0<<0); //toggle update reg
    LPC_SYSCON->MAINCLKUEN = (1<<0); //update clock source again
    while(!(LPC_SYSCON->MAINCLKUEN & (1<<0))); //wait until updated
    LPC_SYSCON->PDRUNCFG |= (1<<7); //disable PLL
  }

  if(pllclksel != 0) //SYS osc
  {
    LPC_SYSCON->PDRUNCFG |= ((1<<0)|(1<<1)); //disable IRC osc
  }
  else //IRC osc
  {
    LPC_SYSCON->PDRUNCFG |= (1<<5); //disable SYS osc
  }

  //set prescaler for backlight PWM
  if(current_clock >= 40000000UL)
  {
    LPC_TMR16B1->PR = 2; //div 4
  }
  else if(current_clock >= 20000000UL)
  {
    LPC_TMR16B1->PR = 1; //div 2
  }
  else
  {
    LPC_TMR16B1->PR = 0; //no prescaler
  }
  LPC_TMR16B1->PC = 0; //reset prescaler

  //set prescaler for adc
  LPC_ADC->CR = (((current_clock/4000000UL)-1)<<8) | (LPC_ADC->CR&0xFFFF00FF);  //stop

  //re-init systick timer
  SysTick_Config(current_clock / 1000); //1000 Hz

  //re-init interface
  if_init(INTERFACE_RESET);

  ENABLE_IRQ();

  return current_clock;
}
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
int main(void)
{
  uint_least16_t a, b, c, d, e;
  uint_least16_t color, fgcolor=RGB(0,0,0), bgcolor=RGB(255,255,255);
  uint_least8_t intf=DEFAULT_INTERF, led_power=DEFAULT_POWER;
  uint_least32_t ms;
#ifdef TP_SUPPORT
  uint_least32_t tp_t=0, tp_int=0, ldr_t=0;
#endif

  //init periphery
  init();

  //set interface
  intf = usersettings->interface;
  ms = get_ms();
  while((GPIO_GETPIN(SS_PORT, SS_PIN) == 0) && ((get_ms()-ms) < 100)) //CS low (100ms timeout)
  {
    if(GPIO_GETPIN(SPI_PORT, MOSI_PIN) == 0) //MOSI low
    {
      intf = INTERFACE_SPI;
    }
    else if(GPIO_GETPIN(UART_PORT, RX_PIN) == 0) //Rx low
    {
      intf = INTERFACE_UART;
    }
    else
    {
      intf = INTERFACE_I2C;
    }
  }

  //init lcd
  lcd_init();

  //check for config data
  if(usersettings->magic != 0xDEADBEEFUL)
  {
    sysclock(DEFAULT_CLOCK); //set system clock to default value
    lcd_clear(bgcolor);
    lcd_drawtext(10, 10, "No config data.", 1, fgcolor, 0, 0);
#if DEFAULT_POWER == 0
    set_pwm(50);
#else
    set_pwm(DEFAULT_POWER);
#endif
    delay_ms(1000);
#ifdef TP_SUPPORT
    cmd_tp_calibrate(fgcolor, bgcolor);
#endif
    cmd_ctrl_save(DEFAULT_INTERF, DEFAULT_BAUD, DEFAULT_ADDR, (DEFAULT_CLOCK/1000000UL), DEFAULT_POWER, DEFAULT_ORDER, fgcolor, bgcolor);
    cmd_lcd_test(fgcolor, bgcolor);
    intf = DEFAULT_INTERF;
  }

  //load config data and init touch panel, encoder, nav switch, interface
  sysclock(usersettings->sysclock*1000000UL);
#ifdef TP_SUPPORT
  if(features & FEATURE_TP)
  {
    tp_init();
  }
  tp_setmatrix(usersettings->tp.a, usersettings->tp.b, usersettings->tp.c, usersettings->tp.d, usersettings->tp.e, usersettings->tp.f, usersettings->tp.div);
#else
  if(features & FEATURE_ENC)
  {
    enc_init();
  }
  if(features & FEATURE_NAV)
  {
    nav_init();
  }
#endif
  fgcolor = usersettings->fgcolor;
  bgcolor = usersettings->bgcolor;
  lcd_clear(bgcolor);
  set_pwm(usersettings->power);
  uart_setbaudrate(usersettings->baudrate);
  i2c_setaddress(usersettings->address);
  if_setbyteorder(usersettings->byteorder);
  if_init(intf);

  //main loop
  while(1)
  {
    ms = get_ms();
#ifdef TP_SUPPORT
    //read ldr and set backlight
    if(features & FEATURE_LDR)
    {
      if(if_available() == 0)
      {
        if((ms - ldr_t) >= DEFAULT_LDRTIME)
        {
          ldr_t = ms;
          led_power = ldr_service(led_power);
        }
      }
    }

    //read touch panel
    if(features & FEATURE_TP)
    {
      if((ms - tp_t) >= tp_int)
      {
        tp_t = ms;
        if(tp_read()) //touch press?
        {
          io_set(FEATURE_TP); //set status + IRQ output
        }
      }
      if(if_available() == 0)
      {
        tp_int = 10; //10ms
        continue;
      }
      else
      {
        tp_int = 50; //50ms (slow down tp read when data is available)
      }
    }
#endif

    c = if_read8();
    switch(c)
    {
      default:
      case CMD_NOP1:
      case CMD_NOP2:
        if_flush();
        break;
      case CMD_SYNC:
        if_write8(CMD_SYNC);
        if_flush();
        break;
      case CMD_VERSION:
        if_writestr(VERSION);
        if_flush();
        break;
      case CMD_TEST:
        if(led_power == 0)
        {
          set_pwm(50);
        }
        cmd_lcd_test(fgcolor, bgcolor);
        if_write8(CMD_TEST);
        if_flush();
        break;
      case CMD_STATUS:
        a = status;
        if_write8(a);
        if_flush();
        io_clr(a);
        break;
      case CMD_FEATURES:
        a  = FEATURE_LCD;
#ifdef TP_SUPPORT
        a |= FEATURE_TP;
        a |= FEATURE_LDR;
        a |= FEATURE_IRQ;
#else
        a |= FEATURE_ENC;
        a |= FEATURE_NAV;
#endif
        if_write8(a);
        if_flush();
        break;
      case CMD_CTRL:
        switch(if_read8())
        {
          case CMD_CTRL_SAVE:      cmd_ctrl_save(if_getinterface(), if_getbaudrate(), if_getaddress(), sysclock(0)/1000000, led_power, if_getbyteorder(), fgcolor, bgcolor);  break;
          case CMD_CTRL_INTERFACE: if_init(if_read8());            break;
          case CMD_CTRL_BAUDRATE:  uart_setbaudrate(if_read32());  break;
          case CMD_CTRL_ADDRESS:   i2c_setaddress(if_read8());     break;
          case CMD_CTRL_BYTEORDER: if_setbyteorder(if_read8());    break;
          case CMD_CTRL_SYSCLOCK:  sysclock(if_read8()*1000000UL); break;
          case CMD_CTRL_FEATURES:
            a = if_read8();
#ifdef TP_SUPPORT
            if(a & FEATURE_TP) { tp_init();  };
            if(a & FEATURE_LDR){ ldr_init(); };
#else
            if(a & FEATURE_ENC){ enc_init(); };
            if(a & FEATURE_NAV){ nav_init(); };
#endif
            features = a;
            break;
        }
        break;
      case CMD_PIN:
        a = if_read8(); //mode
        switch(a)
        {
          case 1: //input
            GPIO_PORT(IO_PORT)->DIR &= (1<<IO_PIN);
            break;
          case 2: //read
            c = (GPIO_GETPIN(IO_PORT, IO_PIN)) ? 1 : 0;
            if_write8(c);
            if_flush();
            break;
          case 3: //output low
            GPIO_PORT(IO_PORT)->DIR |= (1<<IO_PIN);
            GPIO_CLRPIN(IO_PORT, IO_PIN);
            break;
          case 4: //output high
            GPIO_PORT(IO_PORT)->DIR |= (1<<IO_PIN);
            GPIO_SETPIN(IO_PORT, IO_PIN);
            break;
          case 5: //state/irq (touch) low active
            io_config = 0;
            GPIO_PORT(IO_PORT)->DIR |= (1<<IO_PIN);
            GPIO_SETPIN(IO_PORT, IO_PIN);
            break;
          case 6: //state/irq (touch) high active
            io_config = 1;
            GPIO_PORT(IO_PORT)->DIR |= (1<<IO_PIN);
            GPIO_CLRPIN(IO_PORT, IO_PIN);
            break;
        }
        break;
      case CMD_ADC:
        a = if_read8(); //chn
        if_write16(adc_read(a));
        if_flush();
        break;

      case CMD_LCD_LED:
        a = if_read8();
        if(a == 255)
        {
          if_write8(led_power);
          if_flush();
        }
        else
        {
          led_power = set_pwm(a);
        }
        break;
      case CMD_LCD_RESET:
        lcd_init();
        break;
      case CMD_LCD_POWER:
        lcd_power((if_read8()));
        break;
      case CMD_LCD_RAWCMD:
        lcd_wrcmd8(if_read8());
        break;
      case CMD_LCD_RAWDAT:
        lcd_wrdata8(if_read8());
        break;
      case CMD_LCD_ENABLE:
        lcd_enable();
        break;
      case CMD_LCD_DISABLE:
        lcd_disable();
        break;

      case CMD_LCD_ORIENTATION:
        lcd_setorientation(if_read8());
        break;
      case CMD_LCD_WIDTH:
        if_write16(lcd_getwidth());
        if_flush();
        break;
      case CMD_LCD_HEIGHT:
        if_write16(lcd_getheight());
        if_flush();
        break;
      case CMD_LCD_INVERT:
        lcd_invert(if_read8());
        break;
      case CMD_LCD_FGCOLOR:
        fgcolor = if_read16();
        break;
      case CMD_LCD_BGCOLOR:
        bgcolor = if_read16();
        break;
      case CMD_LCD_TERMINAL:
        cmd_lcd_terminal(fgcolor, bgcolor, 1);
        if_write8(CMD_LCD_TERMINAL);
        if_flush();
        break;
      case CMD_LCD_DRAWIMAGE:
        cmd_lcd_drawimage(fgcolor, bgcolor);
        break;

      case CMD_LCD_CLEAR:
        color = if_read16(); //color
        lcd_clear(color);
        break;
      case CMD_LCD_CLEARFG:
        lcd_clear(fgcolor);
        break;
      case CMD_LCD_CLEARBG:
        lcd_clear(bgcolor);
        break;

      case CMD_LCD_DRAWPIXEL:
        a = if_read(); //x
        b = if_read(); //y
        color = if_read16(); //color
        lcd_drawpixel(a, b, color);
        break;
      case CMD_LCD_DRAWPIXELFG:
        a = if_read(); //x
        b = if_read(); //y
        lcd_drawpixel(a, b, fgcolor);
        break;
      case CMD_LCD_DRAWPIXELBG:
        a = if_read(); //x
        b = if_read(); //y
        lcd_drawpixel(a, b, bgcolor);
        break;

      case CMD_LCD_DRAWLINE:
        a = if_read(); //x0
        b = if_read(); //y0
        c = if_read(); //x1
        d = if_read(); //y1
        color = if_read16(); //color
        lcd_drawline(a, b, c, d, color);
        break;
      case CMD_LCD_DRAWLINEFG:
        a = if_read(); //x0
        b = if_read(); //y0
        c = if_read(); //x1
        d = if_read(); //y1
        lcd_drawline(a, b, c, d, fgcolor);
        break;
      case CMD_LCD_DRAWLINEBG:
        a = if_read(); //x0
        b = if_read(); //y0
        c = if_read(); //x1
        d = if_read(); //y1
        lcd_drawline(a, b, c, d, bgcolor);
        break;
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

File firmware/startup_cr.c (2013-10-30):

//*****************************************************************************
// LPC11xx Microcontroller Startup code for use with LPCXpresso IDE
//
// Version : 130808
//*****************************************************************************
//
// Copyright(C) NXP Semiconductors, 2013
// All rights reserved.
//
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
// Permission to use, copy, modify, and distribute this software and its
// documentation is hereby granted, under NXP Semiconductors' and its
// licensor's relevant copyrights in the software, without fee, provided that it
// is used in conjunction with NXP Semiconductors microcontrollers.  This
// copyright, permission, and disclaimer notice must appear in all copies of
// this code.
//*****************************************************************************

#if defined (__cplusplus)
#ifdef __REDLIB__
#error Redlib does not support C++
#else
//*****************************************************************************
//
// The entry point for the C++ library startup
//
//*****************************************************************************
extern "C" {
    extern void __libc_init_array(void);
}
#endif
#endif

#define WEAK __attribute__ ((weak))
#define ALIAS(f) __attribute__ ((weak, alias (#f)))

//*****************************************************************************
#if defined (__cplusplus)
extern "C" {
#endif

//*****************************************************************************
#if defined (__USE_CMSIS) || defined (__USE_LPCOPEN)
// Declaration of external SystemInit function
extern void SystemInit(void);
#endif

//*****************************************************************************
//
// Forward declaration of the default handlers. These are aliased.
// When the application defines a handler (with the same name), this will
// automatically take precedence over these weak definitions
//
//*****************************************************************************
     void ResetISR(void);
WEAK void NMI_Handler(void);
WEAK void HardFault_Handler(void);
WEAK void SVC_Handler(void);
WEAK void PendSV_Handler(void);
WEAK void SysTick_Handler(void);
WEAK void IntDefaultHandler(void);

//*****************************************************************************
//
// Forward declaration of the specific IRQ handlers. These are aliased
// to the IntDefaultHandler, which is a 'forever' loop. When the application
// defines a handler (with the same name), this will automatically take
// precedence over these weak definitions
//
//*****************************************************************************
void CAN_IRQHandler (void) ALIAS(IntDefaultHandler);
void SSP1_IRQHandler (void) ALIAS(IntDefaultHandler);
void I2C_IRQHandler (void) ALIAS(IntDefaultHandler);
void TIMER16_0_IRQHandler (void) ALIAS(IntDefaultHandler);
void TIMER16_1_IRQHandler (void) ALIAS(IntDefaultHandler);
void TIMER32_0_IRQHandler (void) ALIAS(IntDefaultHandler);
void TIMER32_1_IRQHandler (void) ALIAS(IntDefaultHandler);
void SSP0_IRQHandler (void) ALIAS(IntDefaultHandler);
void UART_IRQHandler (void) ALIAS(IntDefaultHandler);
void ADC_IRQHandler (void) ALIAS(IntDefaultHandler);
void WDT_IRQHandler (void) ALIAS(IntDefaultHandler);
void BOD_IRQHandler (void) ALIAS(IntDefaultHandler);
void PIOINT3_IRQHandler (void) ALIAS(IntDefaultHandler);
void PIOINT2_IRQHandler (void) ALIAS(IntDefaultHandler);
void PIOINT1_IRQHandler (void) ALIAS(IntDefaultHandler);
void PIOINT0_IRQHandler (void) ALIAS(IntDefaultHandler);
void WAKEUP_IRQHandler  (void) ALIAS(IntDefaultHandler);

//*****************************************************************************
//
// The entry point for the application.
// __main() is the entry point for Redlib based applications
// main() is the entry point for Newlib based applications
//
//*****************************************************************************
#if defined (__REDLIB__)
extern void __main(void);
#else
extern int main(void);
#endif
//*****************************************************************************
//
// External declaration for the pointer to the stack top from the Linker Script
//
//*****************************************************************************
extern void _vStackTop(void);
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

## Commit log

2012-03-13 updated readme added layout files and images
    [MI0283QT_v10.brd, MI0283QT_v10.sch, MI0283QT_v11.brd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]
2012-04-01 clean-up of schematics
    [MI0283QT_v11.sch]
2013-02-21 added MI0283QT9A schematics + layout
    [MI0283QT_v12.brd, MI0283QT_v12.sch]
2013-05-27 added v2 infos and schematics
2013-06-17 added v2 schematics and layout
    [MI0283QT_v20.brd, MI0283QT_v20.sch]
2013-06-22 added infos to schematics
    [MI0283QT_v20.brd, MI0283QT_v20.sch]
2013-06-22 moved CON2 to bottom
    [MI0283QT_v12.brd]
2013-07-13 fixed interface change time
    [Display_DrawImg_SPI.ino, Display_DrawImg_UART.ino, Display_SPI.ino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]
2013-08-18 updated schematics
    [MI0283QT_v20.sch]
2013-08-20 updated examples and added nav switch example
2013-10-17 I2C address mistake
2013-11-01 LPCXpresso: use non-floating-point printf
2013-12-09 Firmware v0.05
    added interrupt/status output
    type optimization
2013-12-11 bugfix: orientation was not correctly interpreted in touchpanel functions
    [lcd_mi0283qt9.c, lcd_ug12d228aa.c]
2013-12-12 updated cad files to Eagle xml format
    [MI0283QT_v10.brd, MI0283QT_v10.sch, MI0283QT_v11.sch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]
2013-12-12 added new v1.3 schematics and layout
    [MI0283QT_v13.brd, MI0283QT_v13.sch]
2014-01-02 bugfix in drawtext and drawstring
    [main.c, settings.h]
2014-02-07 Bugfix in touch calibration routineBugfix in touch calibration routine
    [main.c, tp.c]
2014-03-10 updated license infos
    [MI0283QT_v10.brd, MI0283QT_v10.sch, MI0283QT_v11.sch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]
2014-08-15 updated schematic and layout files
    [MI0283QT_v10.brd, MI0283QT_v10.sch, MI0283QT_v11.brd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]
2014-08-21 updated layout and schematics
    [MI0283QT_v13.brd, MI0283QT_v14.brd, MI0283QT_v14.sch]
2014-08-28 removed wrong files
    [MI0283QT_v14.brd, MI0283QT_v14.sch]
2014-10-28 firmware v0.07 with SPI as default interface
2014-11-06 cleaned up schematics and layout
    [MI0283QT_v10.brd, MI0283QT_v10.sch, MI0283QT_v11.brd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]
2015-08-21 changed path structure
    [MI0283QT_v10.brd, MI0283QT_v10.sch, MI0283QT_v11.brd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]
2015-12-22 added v1.5
    [MI0283QT_v15.brd, MI0283QT_v15.sch]
2016-03-03 update schematics
    [MI0283QT_v15.brd, MI0283QT_v15.sch]
2016-03-07 updated layout
    [MI0283QT_v15.brd]
2020-07-01 updated PDFs and schematics
    [MI0283QT_v20.brd, MI0283QT_v20.sch]
